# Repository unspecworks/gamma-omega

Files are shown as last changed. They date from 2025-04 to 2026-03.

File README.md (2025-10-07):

# GAMMA OMEGA

A 36 Keys low-profile unibody ergonomic keyboard designed for portability and durability while still maintaining comfort.

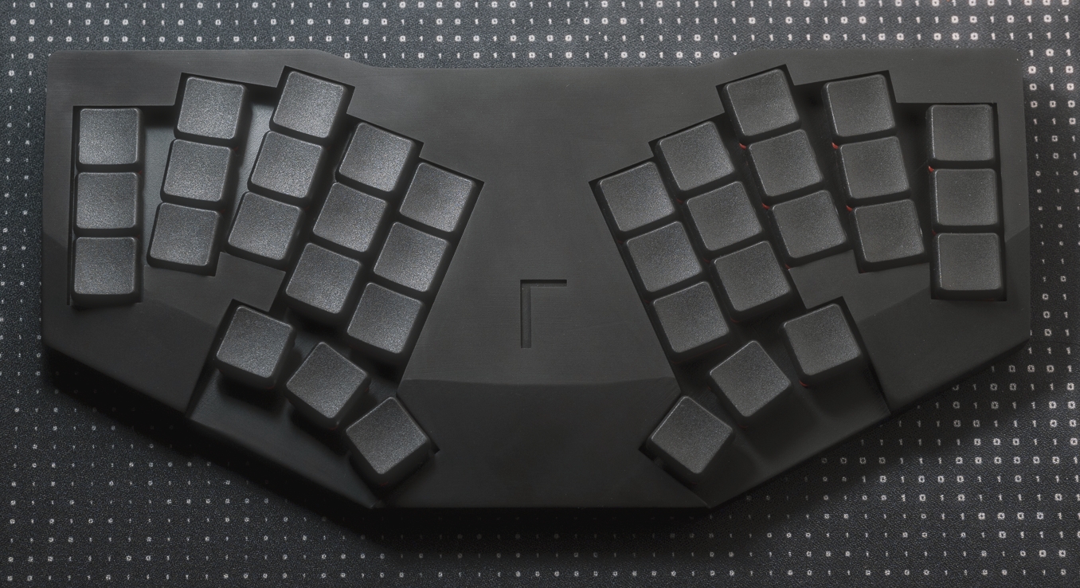
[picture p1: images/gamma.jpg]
Gamma-Omega

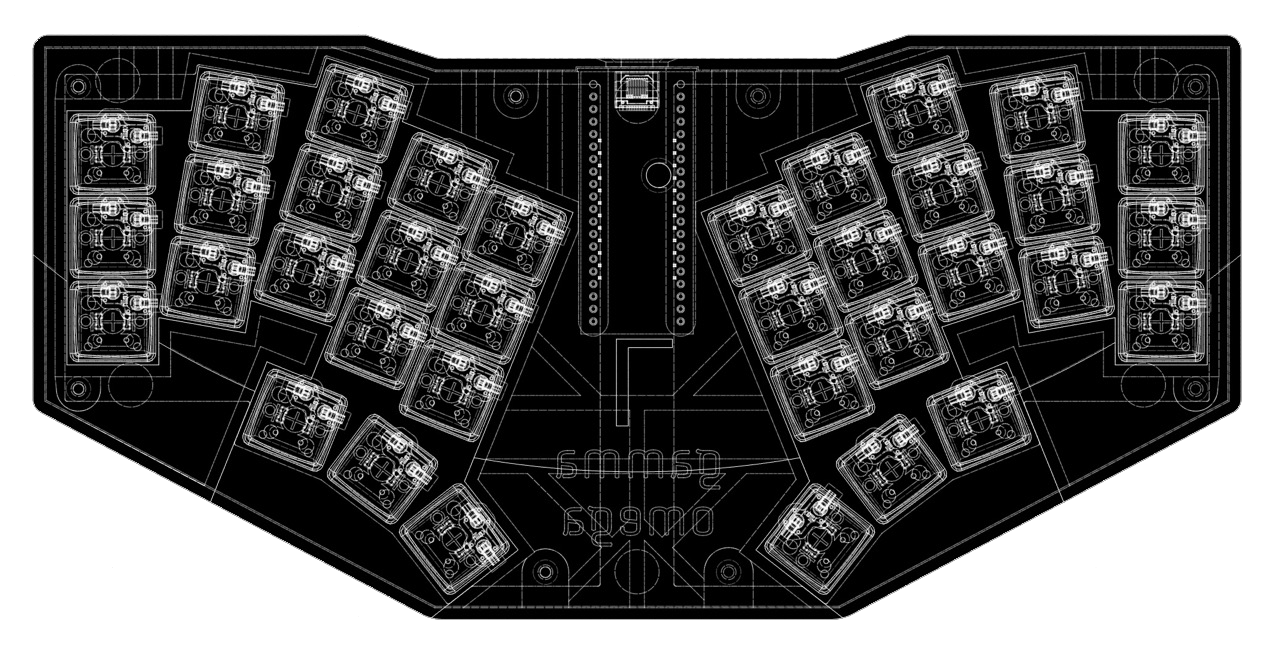
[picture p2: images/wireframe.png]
Gamma-Omega-Wireframe

*Portable? It may not be very compact, but you can still just toss it in your bag, right?*

## Variants
There are currently three variants of Gamma Omega in this repository, all using the same 36-key layout and spacing.

| | Controller | Connection | PCB | Diodes | Roll-over | Switch | Built |
|-|-|-|-|-|-|-|-|
| [Original](/original/) | Raspberry Pi Pico | USB | Twin | 36 | NKRO 🥇 | Choc v1, v2 | :white_check_mark: | 
| [TC36K](/tc36k/) | Raspberry Pi Pico | USB | Mono | 0 | 6KRO 🥈 | Choc v1, v2[^1] | :white_check_mark: |
| [Hesse](/hesse/) | Nice!Nano v2/clone | USB/BLE | Mono | 0 | 4KRO 🥉 | Choc v1, v2 | :construction: |

[^1]: Choc v2 support since the TC36K v1.1.0.

The original and TC36K versions use the same case. The Hesse has a Bluetooth capable MCU controller and a slightly different case for the battery etc.

_See the `README.md` in each folder for more information._

## Technical Details

### Spacing

18 x 17mm (Choc spacing with a tighter grid)

### Dimensions

 - Length: 246mm
 -  Width: 119mm
 - Height: approx. 18mm 
   - feet to keycap (2mm height rubber feet and CFX choc v1 keycap)

### Weight

full built: approx. 301g (Original), 308g (TC36K)

### ergogen

The PCB was generated using [Ergogen](https://github.com/ergogen/ergogen), an ergonomic keyboard generator tool that simplifies the creation of custom keyboard layouts.

## Development Roadmap

- [ ] Support FDM/MJF version case w/ heat set insert method.
- [ ] Cherry MX ULP Switch Variant.

## SPECIAL THANKS 

[@GEIGEIGEIST](https://github.com/GEIGEIGEIST)
- This project was greatly inspired by his work. In particular, TOTEM. [TOTEM](https://github.com/GEIGEIGEIST/totem) is my favorite lo-pro split keyboard. Please check it out.

[Peter Cock](https://github.com/peterjc)
- Thanks for creating and contributing to the TC36k variant.

## Contributing

Contributions are welcome! Feel free to submit pull requests or open issues for any improvements or bug fixes.

The repository uses git-submodules for some footprints, it can easily be setup locally with:

```console
git clone --recurse-submodules https://github.com/unspecworks/gamma-omega.git
```

But I don't know much about modeling and PCB design.

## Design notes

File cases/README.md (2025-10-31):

# Gamma Omega 3DP Case

> [!NOTE]
> Compatible with both [Original](../original/) and [TC36K](../tc36k/) PCBs.

## Bottom case

* **`bottom.step`**
  This version exposes the switch hotswap sockets.

* **`bottom_covered.step`**
  This version conceals the switch hotswap sockets, providing a cleaner appearance.

## Recommendation

For now, it has only been tested with SLA Resin.

### [JLC3DP](https://jlc3dp.com) (JLCPCB)

- 3D Technology: `SLA (Resin)`
- Material: `JLC Black resin`  
- Surface Finish: `General Sanding`

#### If you want the transparent case,

- Material: `8001 Resin`
- Surface Finish: `Oil spray`: Required for full transparency; otherwise the result will be translucent.

> [!TIP]
> You may encounter a few warnings But rest assured, you're good to go.

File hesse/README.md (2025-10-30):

# Gamma-Omega Hesse - BlueTooth mono PCB without diodes

## Quick Links
- [3D Printable Case](cases/) (which are *different* to the original Gamma Omega and TC36K):
- [PCB](pcb/) including the Gerbers ZIP file for getting the PCB fabricated at JLCPLC or similar,
  and BOM & position files which might work for assembly with the hot-swap sockets (untested as the
  parts were not available).
- [Ergogen Configuration](ergogen/README.md) 
- Firmware (which is *different* to the original Gamma Omega and the TC36K):
    - [Hesse ZMK Firmware](https://github.com/peterjc/zmk-keyboard-graph-theory/tree/main/boards/shields/hesse)
- [Build Guide](BUILD_GUIDE.md)

## Photos

Pending, but it looks like the original Gamma Omega - the key placement, PCB outline
and case outline remain the same. However the reset button is now on the top edge along
from the USB connector.

## PCB design

This iteration of the Gamma Omega family of 36-key keyboards is the first wireless one
which supports BlueTooth, specifically BlueTooth Low Energy (BLE) using ZMK firmware.
This meant a change in the controller, as even through the Raspberry Pi Pico W boards
might work, their Bluetooth module is not yet supported in ZMK, and they are much more
battery hungry than the controllers typically used with ZMK.

In order to stick with a diode-free Graph Theory wiring design, I really wanted a
BlueTooth controller with built in LiPo battery charging *and* at least 26 GPIO pins
to follow the same partial *Tutte Coxeter graph* wiring as used in the
[Gamma Omega TC36K](../tc36k/README.md) with 6-key roll over.

Instead, this design uses a [Nice!Nano v2](https://nicekeyboards.com/nice-nano)
or the [SuperMini NRF52840](https://kriscables.com/supermini-nrf52840/) aka
[ProMicro NRF52840](https://www.nologo.tech/product/otherboard/NRF52840.html).
These have built in BlueTooth, LiPo battery charging, ZMK support, but "only"
21 GPIO pins. The compromise means using a bipartite girth 6 graph of 21
vertices and 36 edges, giving *only 4-key roll over*. This is the *Hesse
Configuration Incidence Graph*, also known as the [incidence graph of the
affine plane of order 3](https://houseofgraphs.org/graphs/44164).

It looks like the original Gamma Omega - the key placement, PCB outline and
case outline remain the same. However the case moves the reset button to the
top edge along from the USB connector, and internally adds a battery
compartment. ZMK deep sleep is used in lieu of a physical on/off switch.

## Credits

[triliu/Heawood42](https://github.com/triliu/Heawood42) - the first no-diode keyboard using graph theory (42 key split)

[triliu/JESK56](https://github.com/triliu/JESK56) - later no-diode 56 key monoblock keyboard using graph theory

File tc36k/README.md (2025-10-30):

# Gamma-Omega TC36K - USB mono PCB without diodes

## Quick Links
- [3D Printable Case](../cases/)
- [PCB](pcb/) including the Gerbers ZIP file for getting the PCB fabricated at JLCPLC or similar,
  and BOM & position files which might work for assembly with the hot-swap sockets (untested as the
  parts were not available).
- [Ergogen Configuration](ergogen/README.md) 
- Firmware (which is *different* to the original Gamma Omega):
    - [TC36K QMK/VIAL Implementation](https://github.com/peterjc/qmk_userspace/tree/main/keyboards/tutte_coxeter_36k/)
    - [TC36K ZMK Firmware](https://github.com/peterjc/zmk-keyboard-graph-theory/tree/main/boards/shields/tc36k)
- [Build Guide](BUILD_GUIDE.md)

## Photos

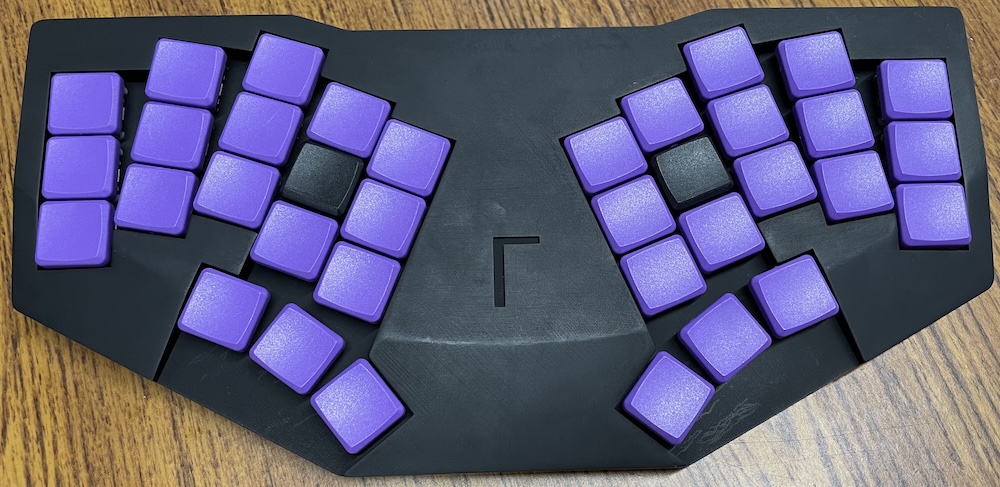
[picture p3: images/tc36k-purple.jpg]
Assembled Gamma Omega TC36K keyboard in black and purple
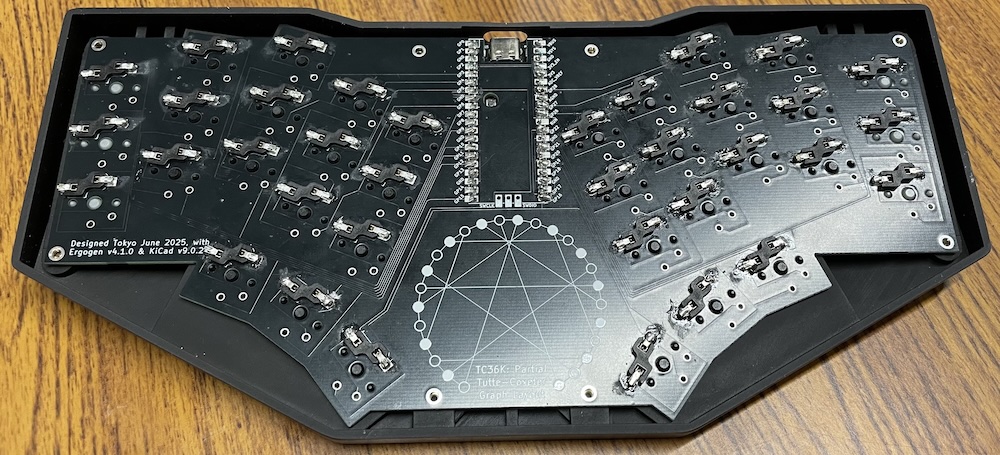
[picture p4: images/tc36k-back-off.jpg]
Inside the Gamma Omega TC36K with the bottom case off showing the no-diode PCB
 

## PCB design

The [original Gamma-Omega](../original/) has a left & right PCB (with the same reversible design),
joined at the middle with the controller daughter board itself.

The *Gamma Omega TC36K* is an alternative larger single PCB design, intended to fit the same case.
Larger PCBs are more expensive, doubly so with the typical minimum order of five - so why do this?
This is a [no-diode design using graph theory to have a 36 key keyboard using only 26 GPIO
pins](https://astrobeano.blogspot.com/2025/05/ergo-mech-keyboard-wiring-using-tutte-coxeter-graph.html).
The cost saving for no diodes is minimal, but with far less parts and soldering,
this design should be quicker and easier to assemble.

Specfically, it uses a partial *Tutte Coxeter graph*, with only 26/30 nodes/vertices/pins,
and 36/45 edges/switches/keys (thus "TC36K"), but still girth 8 for 6-key rollover. 
This needs _different_ firmware to the original Gamma Omega design, see
[Tutte Coxeter 36K firmware (QMK)](https://github.com/peterjc/qmk_userspace/tree/main/keyboards/tutte_coxeter_36k)
or using [ZMK](https://github.com/peterjc/zmk-keyboard-graph-theory/tree/main/boards/shields/tc36k).

## Credits

[triliu/Heawood42](https://github.com/triliu/Heawood42) - the first no-diode keyboard using graph theory (42 key split)

[triliu/JESK56](https://github.com/triliu/JESK56) - later no-diode 56 key monoblock keyboard using graph theory

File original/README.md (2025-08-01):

# Gamma-Omega Original

## Quick Links
- [3D Printable Case](../cases/)
- [PCB](pcb/) 
- [Ergogen Configuration](ergogen/README.md) 
- Firmwares
    - [QMK/VIAL Implementation](firmwares/QMK/gamma_omega/)
    - [ZMK Firmware](https://github.com/unspecworks/zmk-config-gamma-omega)
- [Build Guide](BUILD_GUIDE.md)

## Photos

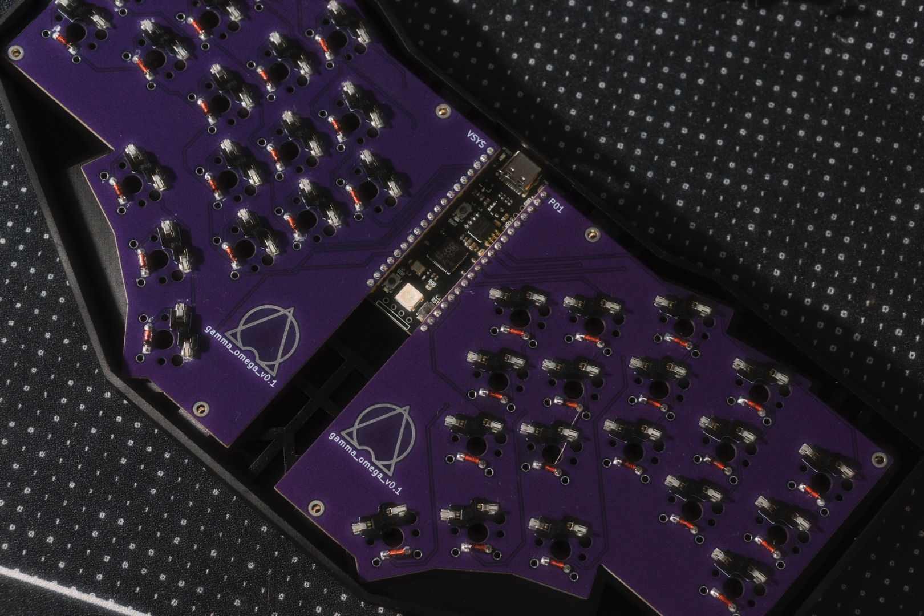
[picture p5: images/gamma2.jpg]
Two PCBs inside the original Gammma Omega
The original Gamma Omega keyboard 

## PCB design

This uses two identical reversible PCBs for the two halves of the keyboard, joined at the RP2040 controller.
This means some pins cannot be used as there isn't a matching pin on the other side,
for example GP0 and GP1 are opposite voltage pins.

This diagram sketches the [GPIO usage](../images/black-raspberry-pi-pico-pins.png)
(red and blue coloring following the convention for the two sides of the PCB).

The design assumes a specific Raspberry Pi Pico variant with GPIOs on pins 35 and 37 (GP29 and GP23),
which are not available on the original board design.
However the pairs GP13/18, GP14/17, and GP15/16 at the bottom of the board are unused,
so in theory the PCB could use those instead for compatibility with the original pin allocation.

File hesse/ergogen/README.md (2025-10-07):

# gamma-omega-hesse - Ergogen files

This is based on the [ergogen](https://github.com/ergogen/ergogen) configuration file
at `../../tc36k/config.yaml` which describes the Gamma-Omega TC36K keyboard mono PCB.
The changes are to use a smaller "Nice!Nano v2" controller (or the "SuperMini NRF52840"
aka "ProMicro52840" clone), which has Bluetooth but less GPIO pins and thus a different
wiring net. We also make a cut out for the inclusion of a battery, and a JST battery
connector, and a reset button (but no power switch in the initial version).
Otherwise the PCB outline and switch placement should be unchanged.

Run ergogen on the whole folder to get it to look at the footprints:

```console
❯ ergogen gc36k/ergogen/
Ergogen v4.1.0 CLI

Analyzing folder...
Interpreting format: YAML
Preprocessing input...
Checking compatibility...
Calculating variables...
Parsing points...
Generating outlines...
Modeling cases...
Scaffolding PCBs...
Writing output to disk...
Done.
```

To merge any changes with the manually routed PCB, try [Ergogen
Helper](https://github.com/infused-kim/kb_ergogen_helper):

```
❯ cp output/pcbs/gamma-omega-hesse.kicad_pcb hesse/pcb/gamma-omega-hesse-routed-new.kicad_pcb && \
    /Applications/KiCad/KiCad.app/Contents/Frameworks/Python.framework/Versions/Current/bin/python3 \
    resources/kb_ergogen_helper/ergogen_helper.py copy-traces \
    hesse/pcb/gamma-omega-hesse-routed.kicad_pcb hesse/pcb/gamma-omega-hesse-routed-new.kicad_pcb
```

## Credits

[triliu/Heawood42](https://github.com/triliu/Heawood42) - the first no-diode keyboard using graph theory (42 key split)

[triliu/JESK56](https://github.com/triliu/JESK56) - later no-diode 56 key monoblock keyboard using graph theory

[infused-kim/kb_ergogen_fp](https://github.com/infused-kim/kb_ergogen_fp) - Awesome footprints and 3d models.

[ceoloide/ergogen-footprints](https://github.com/ceoloide/ergogen-footprints) - Also wonderful footprints!!

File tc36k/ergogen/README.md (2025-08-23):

# gamma-omega-tc36k - Ergogen files

The original Gamma-Omega design has a left & right PCB (with the same reversible design),
joined at the middle with the controller daughter board itself.
The original [ergogen](https://github.com/ergogen/ergogen) configuration file at
`../../original/ergogen/config.yaml` described the Gamma-Omega keyboard double-sided twin PCB design.

That was modified, initially using mirroring to make a single 36 key PCB.
It now uses a full 40-pin Raspberry Pi Pico controller footprint.
That required enlarging the top edge of the PCB by 2mm, which now matches the controller.
This still fits in the same case.
The wiring net is defined using a partial Tutte-Coxeter graph,
with 26/30 nodes/vertices/pins and 36/45 edges/switches/keys.

Run ergogen on the whole folder to get it to look at the footprints:

```console
❯ ergogen tc36k/ergogen/
Ergogen v4.1.0 CLI

Analyzing folder...
Interpreting format: YAML
Preprocessing input...
Checking compatibility...
Calculating variables...
Parsing points...
Generating outlines...
Modeling cases...
Scaffolding PCBs...
Writing output to disk...
Done.
```

## Credits

[triliu/Heawood42](https://github.com/triliu/Heawood42) - the first no-diode keyboard using graph theory (42 key split)

[triliu/JESK56](https://github.com/triliu/JESK56) - later no-diode 56 key monoblock keyboard using graph theory

[infused-kim/kb_ergogen_fp](https://github.com/infused-kim/kb_ergogen_fp) - Awesome footprints and 3d models.

[ceoloide/ergogen-footprints](https://github.com/ceoloide/ergogen-footprints) - Also wonderful footprints!!

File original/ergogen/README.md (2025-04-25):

# gamma-omega ergogen
Configuration files and custom footprints for creating PCBs using [ergogen](https://github.com/ergogen/ergogen).

My custom footprints have many uncommented modifications, so I don't recommend using them separately. Eventually, I plan to organize these properly in a separate repository.

Anyway! Please check out the amazing tool called ergogen and try it for yourself. 

## Credits

[infused-kim/kb_ergogen_fp](https://github.com/infused-kim/kb_ergogen_fp) - Awesome footprints and 3d models.

[ceoloide/ergogen-footprints](https://github.com/ceoloide/ergogen-footprints) - Also wonderful footprints!!

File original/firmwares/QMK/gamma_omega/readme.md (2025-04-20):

# gamma_omega

*A short description of the keyboard/project*

* Keyboard Maintainer: [unspecworks](https://github.com/unspecworks)
* Hardware Supported: *The PCBs, controllers supported*
* Hardware Availability: *Links to where you can find this hardware*

Make example for this keyboard (after setting up your build environment):

    make gamma_omega:default

Flashing example for this keyboard:

    make gamma_omega:default:flash

See the [build environment setup](https://docs.qmk.fm/#/getting_started_build_tools) and the [make instructions](https://docs.qmk.fm/#/getting_started_make_guide) for more information. Brand new to QMK? Start with our [Complete Newbs Guide](https://docs.qmk.fm/#/newbs).

## Bootloader

Enter the bootloader in 3 ways:

* **Bootmagic reset**: Hold down the key at (0,0) in the matrix (usually the top left key or Escape) and plug in the keyboard
* **Physical reset button**: Briefly press the button on the back of the PCB - some may have pads you must short instead
* **Keycode in layout**: Press the key mapped to `QK_BOOT` if it is available

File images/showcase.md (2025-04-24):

# showcase
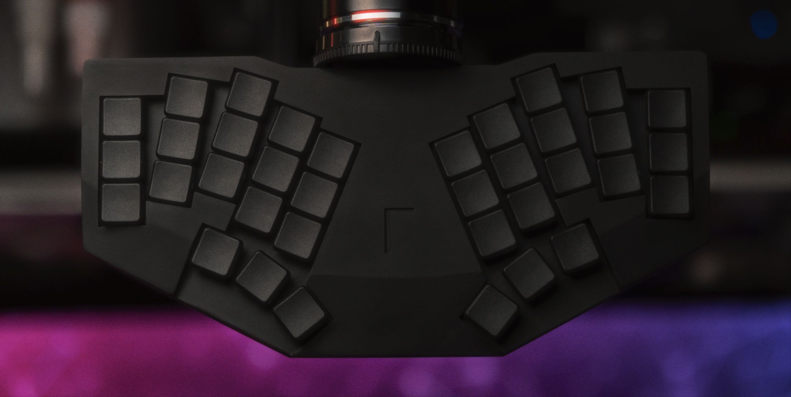
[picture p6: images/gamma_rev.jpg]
hi

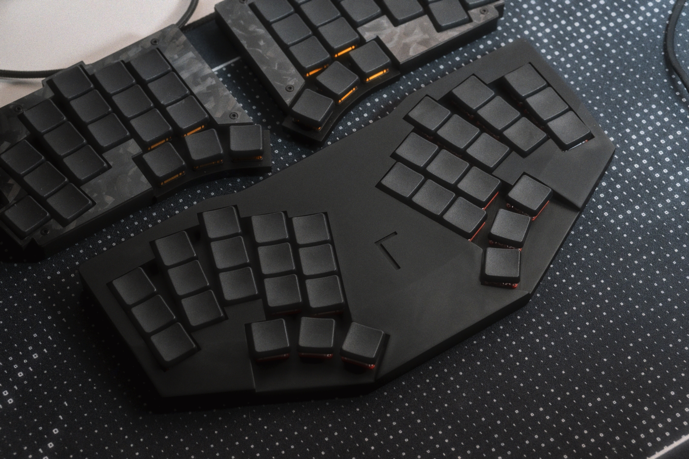
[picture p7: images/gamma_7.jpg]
g

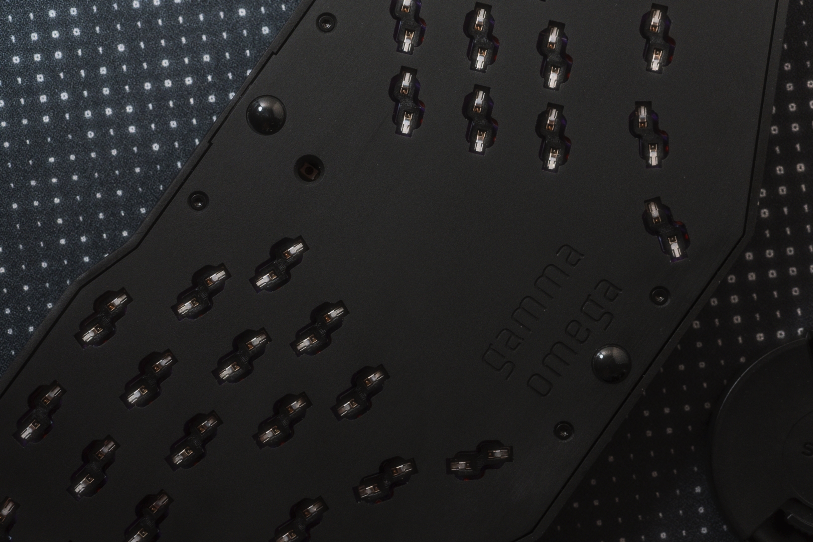
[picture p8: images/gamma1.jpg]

m
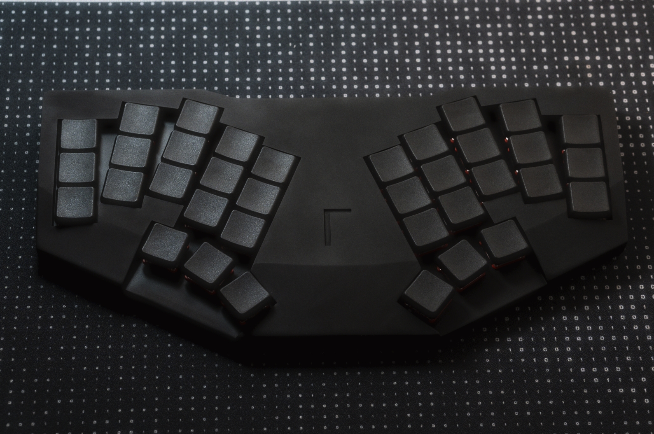
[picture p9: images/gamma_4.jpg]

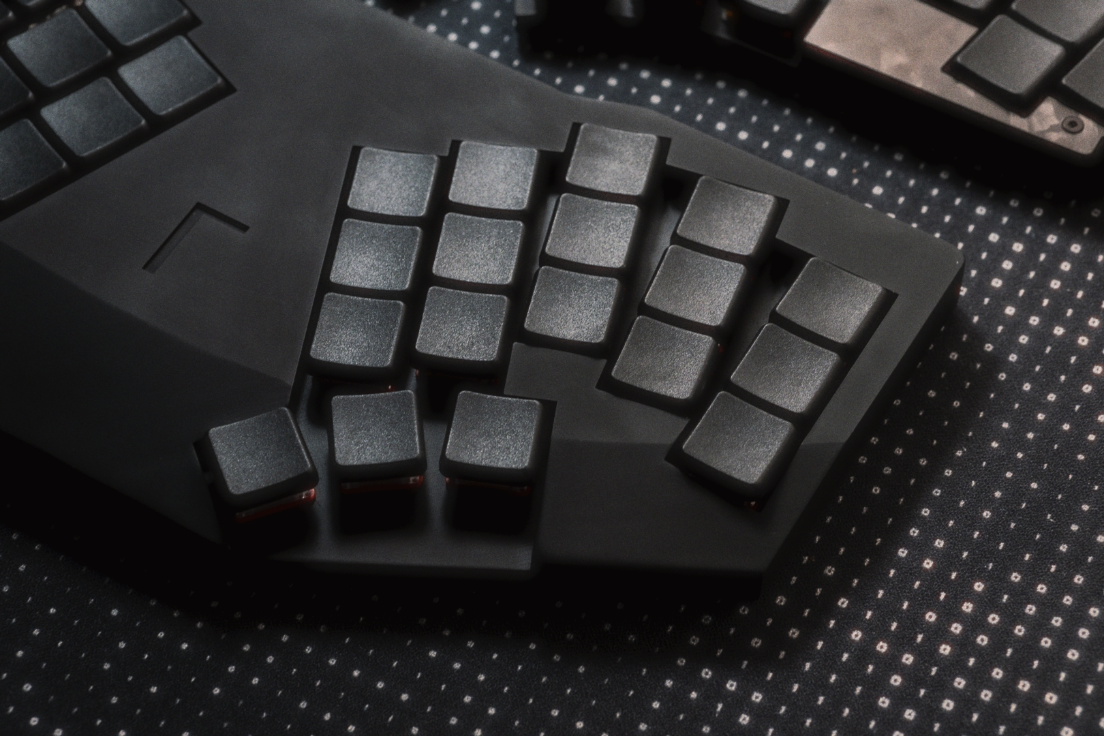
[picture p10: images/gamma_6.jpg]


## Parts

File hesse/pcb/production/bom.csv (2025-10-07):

Designator | Footprint | Quantity | Value | LCSC Part #
JST1 | battery_connector_jst_ph_2 | 1 |  | C157932
RST1 | reset_switch_1825027-8 | 1 |  | C266196
S1, S10, S11, S12, S13, S14, S15, S16, S17, S18, S19, S2, S20, S21, S22, S23, S24, S25, S26, S27, S28, S29, S3, S30, S31, S32, S33, S34, S35, S36, S4, S5, S6, S7, S8, S9 | switch_choc_v1_v2 | 36 |  | C5333465

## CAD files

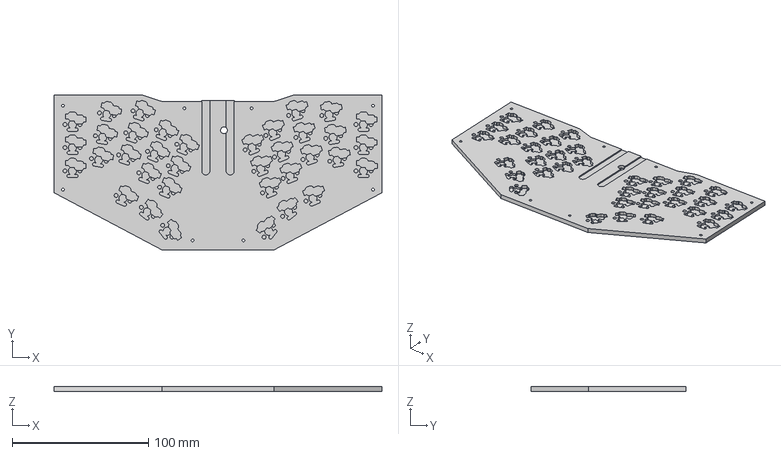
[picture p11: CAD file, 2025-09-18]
cases/bottom_covered.step
240.4 x 113.5 x 3.40 mm

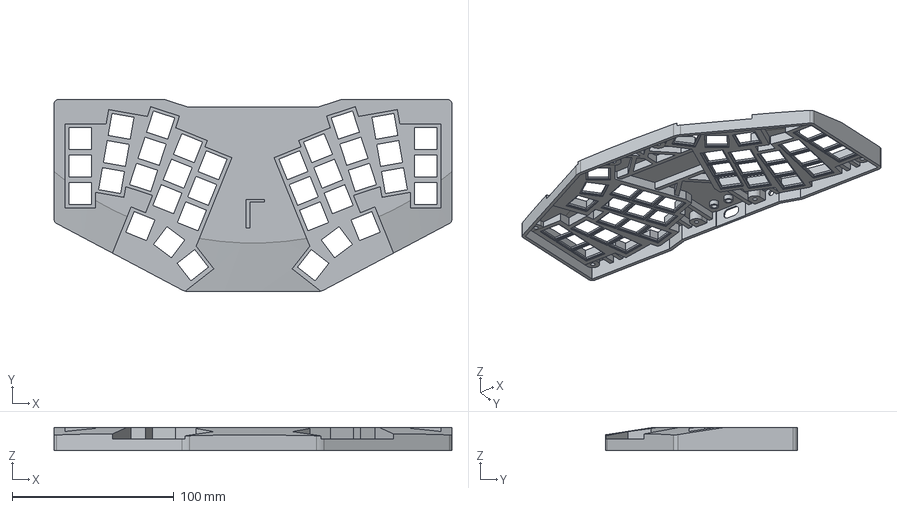
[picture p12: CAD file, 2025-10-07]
hesse/cases/top-hesse.step
245.8 x 118.9 x 14.5 mm

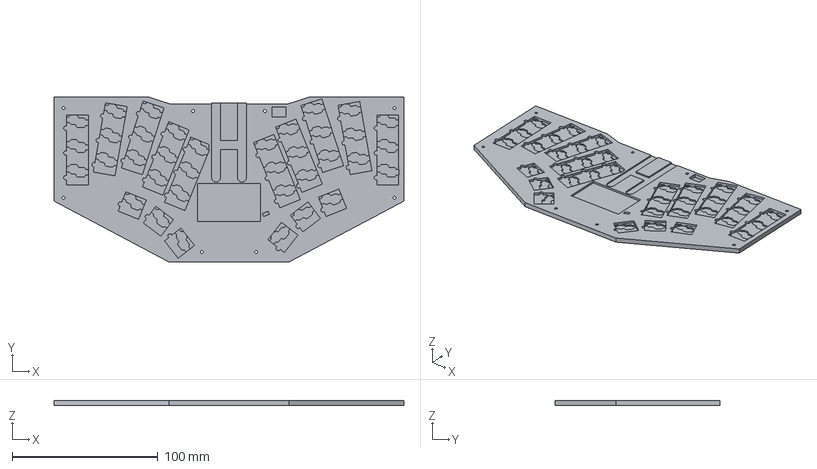
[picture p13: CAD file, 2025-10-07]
hesse/cases/bottom-hesse.step
240.4 x 113.5 x 3.40 mm

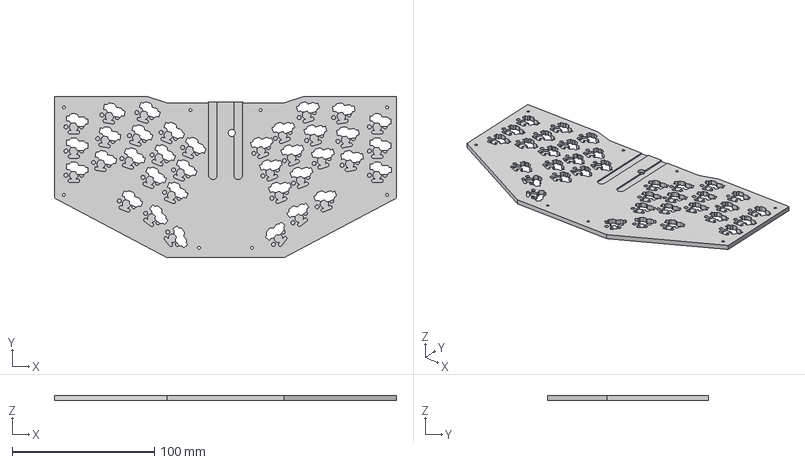
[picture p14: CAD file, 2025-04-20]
cases/bottom.step
240.4 x 113.5 x 3.40 mm

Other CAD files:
cases/top.step

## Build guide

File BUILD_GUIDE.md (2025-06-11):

# Parts List
| Part | Quantity | Details | Source |
|---|---|---|---|
| M2x2 Insert nut | 4 | 2mm length, 3.0mm diameter | |
| M2x6 Insert nut | 4 | 6mm length, 3.0mm diameter | |
| M2x6 Countersunk screw | 4 | 6mm length | |
| M2x8 Countersunk screw | 4 | 8mm length (or 6mm × 8) | |
| Feet bumpons | 6 | 8mm diameter, any height. | |
| 1n4148 diode | 36 |  | [Aliexpress](https://a.aliexpress.com/_oCcCwmR) |
| Kailh Choc PG1350 HotSwap Sockets | 36 | | |
| Kailh Choc switches | 36 | PG1350 | *BUT* |
| Keycap | 36 | MBK, CFX or | |
| Gamma Omega PCB | 2 | 1.6mm thickness | JLCPCB |
| Top case | 1 | SLA Resin | JLC3DP |
| Bottom case | 1 | SLA Resin | JLC3DP |
| Pi Pico USB-C RP2040 | 1 | YD-RP2040 Variants are tested. [Info](https://circuitpython.org/board/vcc_gnd_yd_rp2040/) | [Aliexpress](https://a.aliexpress.com/_opuRQZl) |

> [!NOTE]
> This *requires* a variant of the original Pi Pico design with 28 GPIOs available (GP29 and GP23 on pins 35 and 37).
> The bottom case has a hole allowing access to the boot button on the RP2040 controller, which is mounted facing down once fully assembled.
> The placement of any boot/reset/user buttons varies between boards, even if they are pin-compatible.
> The expected placement (looking at the controller chips upward with the USB and pin 1 at the top) is on the left near pins 7, 8 & 9 (GP5, GND & GP6).
> This is the "black" controller at the Ali Express link:
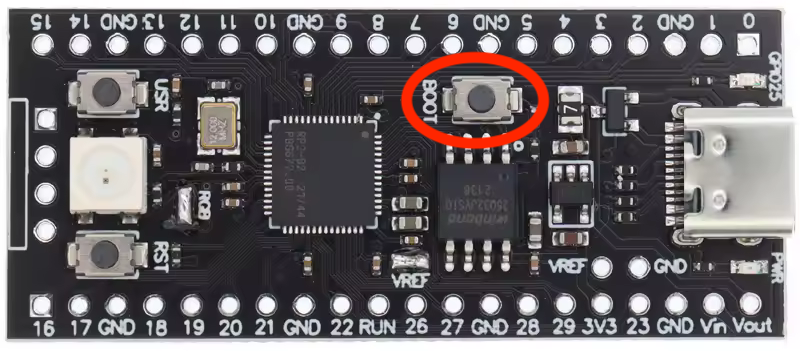
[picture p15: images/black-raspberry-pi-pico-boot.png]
YD_PR2040 "black" Pi Pico microcontroller
> 

> [!TIP]
> Actually, the PCB is compatible with choc v2 and Lofree POM switches. However, since the key spacing is 18x17mm, there may be issues with keycap compatibility. Please keep this in mind.

## Tools

- Soldering tools.
- Safety gears.
- epoxy adhesive
    - or cyanoacrylate adhesive would be fine too for fixing inserts.

> [!WARNING]
> For your safety: Wear protective eyewear, be cautious of hot components, and ensure proper ventilation to avoid inhaling toxic fumes.

# Build Guide

## Diodes Installation
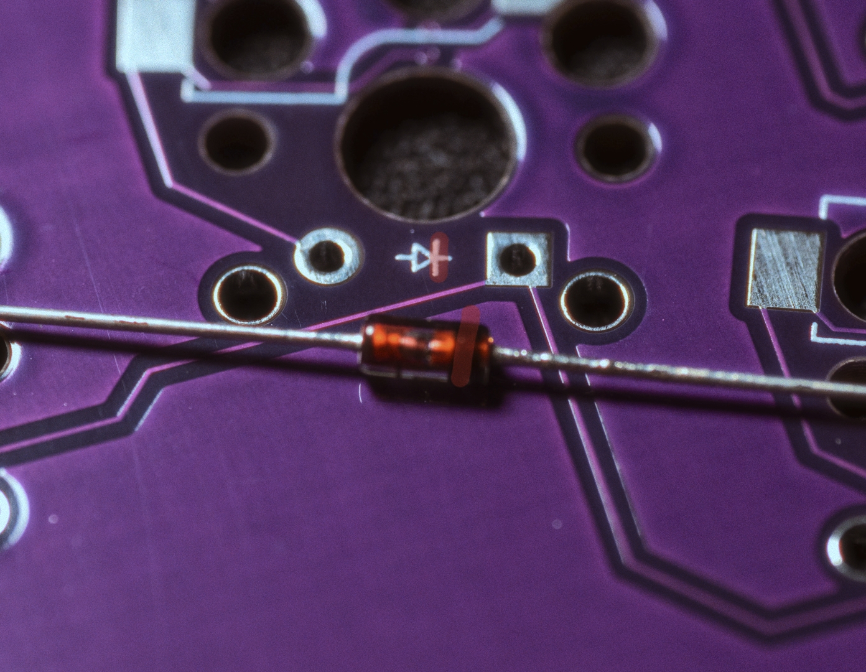
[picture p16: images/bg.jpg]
Diode

> [!IMPORTANT]
> Install diodes with their direction matching the PCB silkscreen markings

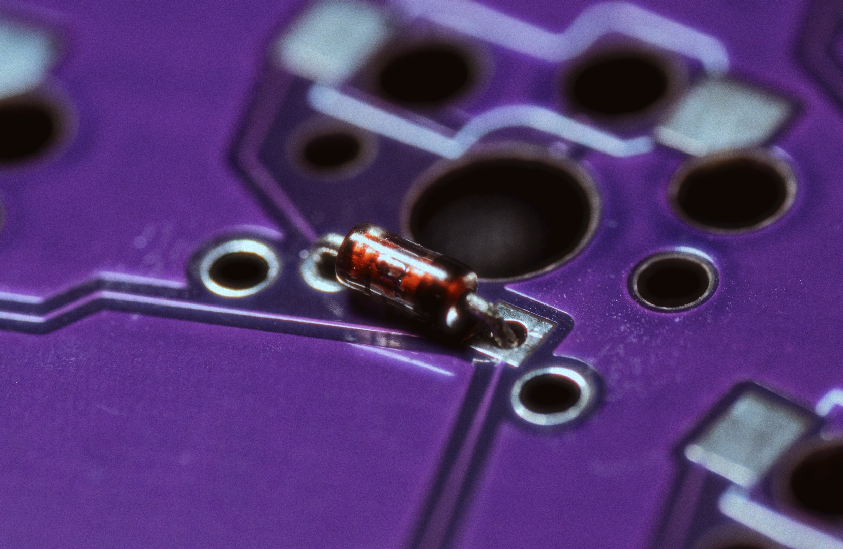
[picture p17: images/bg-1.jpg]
diode2

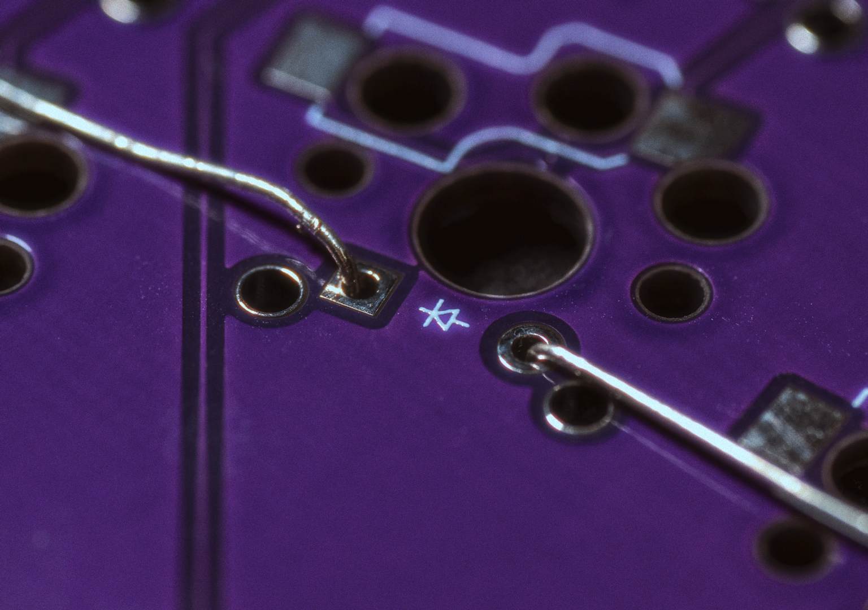
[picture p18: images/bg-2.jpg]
diode3


1. Install diodes carefully, paying close attention to the correct orientation.
2. The direction of the diode must match the silkscreen markings on the PCB.
3. Ensure all diodes are mounted flat against the PCB and aligned straight between the holes.

## Hotswap Socket Installation
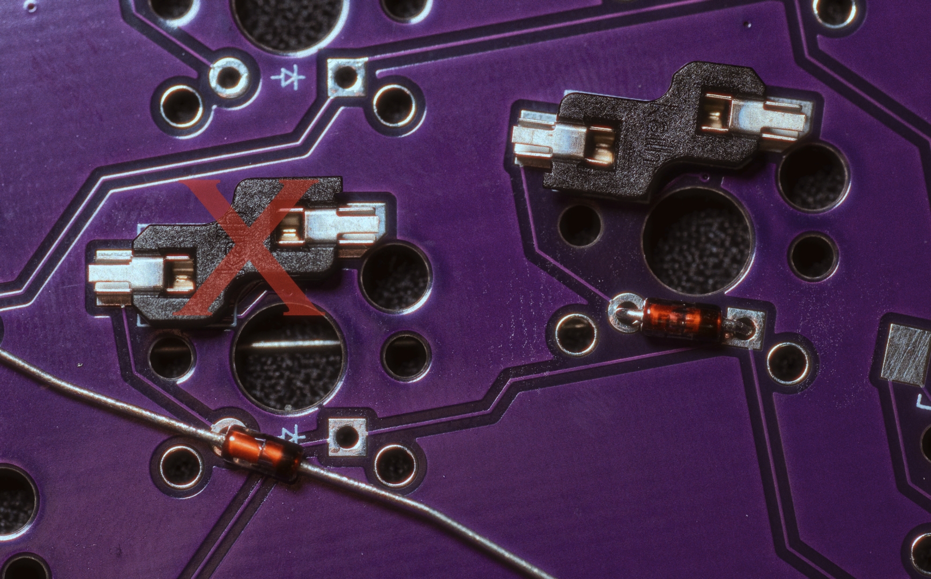
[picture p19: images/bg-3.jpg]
hotswap


1. Install hotswap sockets according to the PCB markings.
2. Ensure correct orientation of the sockets; while they can physically fit in either direction, the bottom case cutouts are designed for the correct orientation only.

## Pi Pico Installation
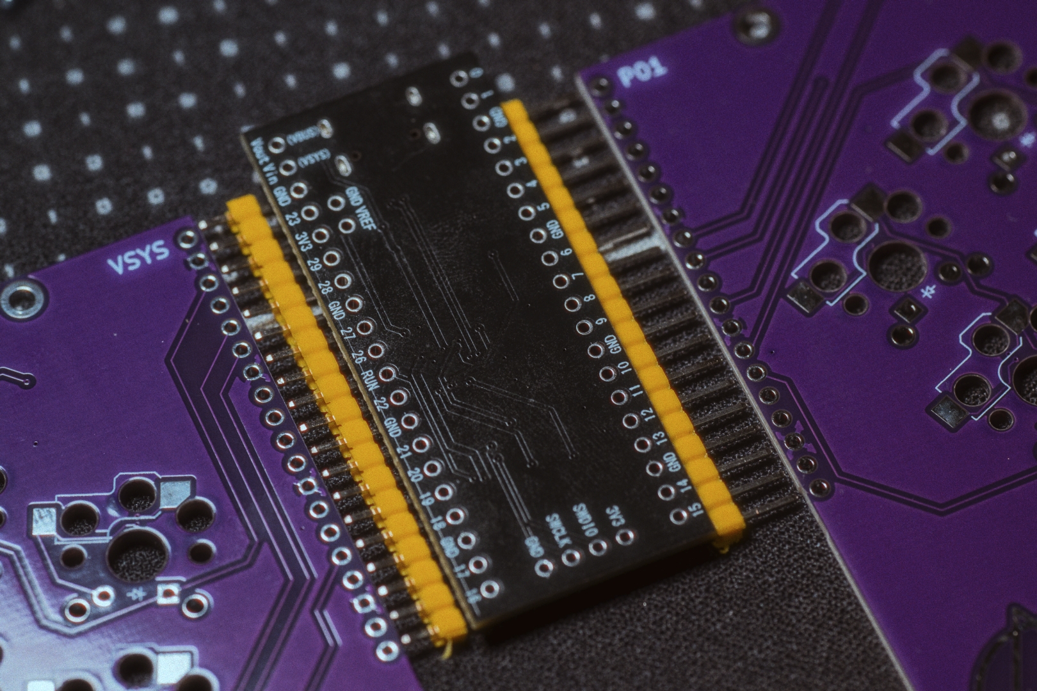
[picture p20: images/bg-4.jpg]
pico


1. Install the Pi Pico on the UP side of the PCB (opposite from where sockets and diodes are installed).
2. Position the Pi Pico with its components facing down toward the PCB and the USB port facing outward.
3. Use two 2.54mm × 19-pin headers (typically with ~2.5mm height insulators) to solder the Pi Pico onto the PCB.

> [!NOTE]
> Do not solder the top left and right pins (the ones closest to the USB port).

> [!WARNING]
> Once soldered, the two PCBs are held together by only a few points. Please be careful when handling them, as they can be easily damaged before being placed in the case

4. After soldering, carefully trim all protruding pins with a nipper.

> [!CAUTION]
> For your safety, please wear safety glasses — trimmed pins can be sharp and may fly off during cutting.

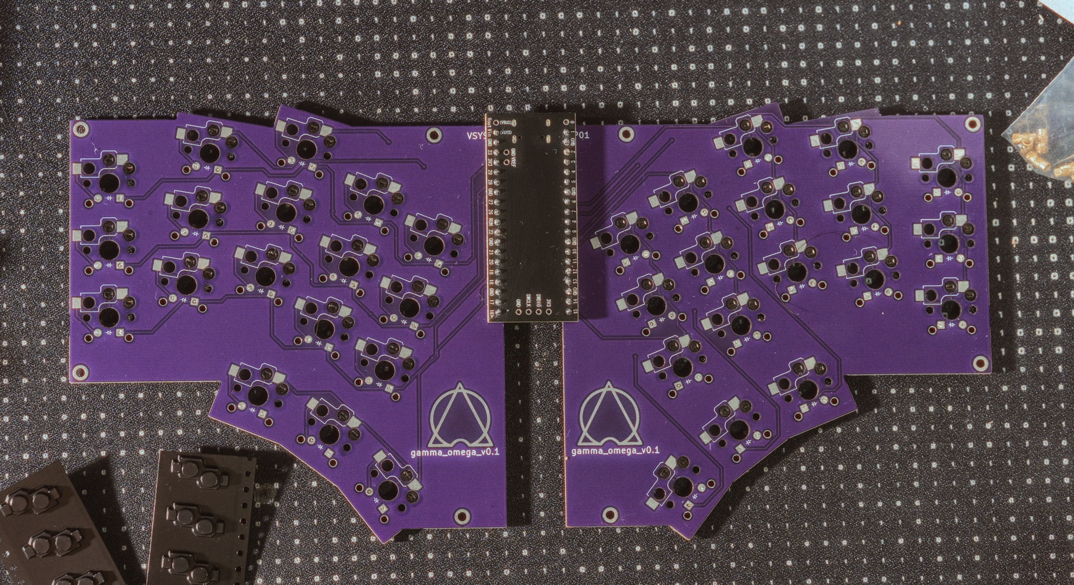
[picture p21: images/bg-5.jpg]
final-pcb

*Your PCB should look like this when completed*

## Firmware Flashing
1. Press and hold the `BOOT` button while connecting the keyboard to your computer.
2. Release the `BOOT` button when a Mass Storage device named "RPI-RP2" appears.
3. Copy the `gamma_omega_vial.uf2` firmware file to this storage device.
4. The storage will disconnect automatically, and the device will function as a keyboard when the firmware is successfully installed.

## Testing
Use your favorite keystroke tester (or Vial's Key matrix tester) with a conductive tweezer to verify that all keys are working properly.

## Case Assembly
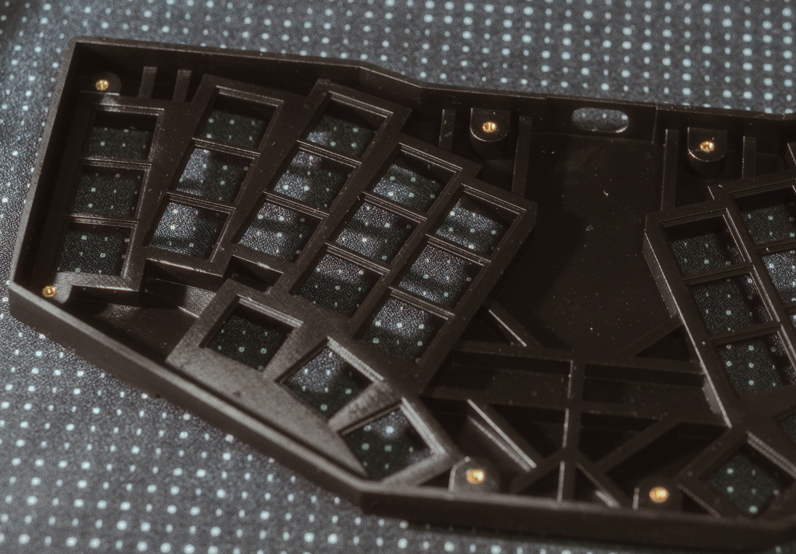
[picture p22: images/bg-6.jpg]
topcase


1. Install 6mm threaded inserts with epoxy adhesive on the top case (upper side, near the USB port hole).
2. Install 2mm threaded inserts with epoxy adhesive on the top case (lower side, opposite the USB port hole).

put-pcb

3. Place the PCB onto the top case.
4. Install switches into the top case while holding the PCB (hotswap sockets) in place.
5. Place the bottom case onto the top case assembly.
6. Secure with screws (8mm or 6mm for upper side, 6mm for lower side).
> [!CAUTION]
> Do not overtighten: the screws only need to support the bottom case's weight.

## DONE!
back
front

### Everything is done.

how does it feel? Comfortable? Any issues? Does it work as you expected?

Whatever the result, I’d really appreciate it if you shared your experience with the community.

Thank you for building it!

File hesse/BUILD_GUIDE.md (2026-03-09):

# Hesse Build guide

Looking for the [original's build guide](../original/BUILD_GUIDE.md),
or the [TC36K's build guide](../tc36k/BUILD_GUIDE.md)?

# Parts List
| Part | Quantity | Details | Source |
|---|---|---|---|
| M2x2x3 Insert nut | 4 | M2 thread, 2mm length, 3.0mm outer diameter | |
| M2x6x3 Insert nut | 4 | M2 thread, 6mm length, 3.0mm outer diameter | |
| M2x6 Countersunk screw | 4 | 6mm length | |
| M2x8 Countersunk screw | 4 | 8mm length (or 6mm × 8) | |
| Feet bumpons | 6 | 8mm diameter, any height. | |
| Kailh Choc PG1350 HotSwap Sockets | 36 | 💡 |
| Kailh Choc switches | 36 | PG1350 | 💡 |
| Keycap | 36 | MBK, CFX, THCS, ... | |
| Gamma Omega Hesse PCB | 1 | 1.6mm thickness | JLCPCB |
| Hesse Top case | 1 | SLA Resin | JLC3DP |
| Hesse Bottom case | 1 | SLA Resin | JLC3DP |
| 6x6x8H right angle reset switch | 1 | 90 degree reset switch like [Tyco Electronics (TE) 1825027-8](https://www.te.com/en/product-1825027-8.html), with a sideways 6x6mm base and 8mm from back of base to end of the button. | e.g. [AliExpress](https://www.aliexpress.com/item/4000275201465.html) |
| JST connector | 1 | JST PH 2.0mm | |
| 3.7V LiPo battery | 1 | eg 500mAh LP702035 with JST connector | 💡 |
| Nice!Nano v2 or clone | 1 | The [SuperMini NRF52840](https://kriscables.com/supermini-nrf52840/) aka [ProMicro NRF52840](https://www.nologo.tech/product/otherboard/NRF52840.html) is tested. | [Offical](https://nicekeyboards.com/nice-nano#find-a-store), [AliExpress](https://www.aliexpress.com/item/1005006035267231.html) |
| Pin headers/diode legs | 35+ | Use the headers included with the controller |  |

> [!WARNING]
> The PCB design mounts the controller face up directly on the PCB, faux-castellated style.
> This is not easy for a novice at soldering.

> [!NOTE]
> The mounting holes for the extra middle trio of pins are different between the Nice!Nano v2 and clones.
> Using a clone controller requires bridging this with bent pins.

> [!NOTE]
> No-stabilizer Choc v2 switches work too, the central hole is large enough.
> However, since the key spacing is 18x17mm, there are not many compatible keycaps.
> Consider the Tai Hao "THCS" or square "MT 165" with the cross stem option.

> [!TIP]
> This PCB allows directly soldering the choc switches (rotated 180 degrees) without using hot-swap sockets.
> However, that will not work with the suggested case bottom (which has hot-swap cut-outs).

> [!TIP]
> The battery compartment will take a 300mAh LP602030 3.7V LiPo battery with ample space to spare.
> A 500mAh LP702035 500mAh should fit comfortably and is suggested, but as yet untested.
> If you want so push it, the largest that might fit is probably a LP802040 - 650mAh,
> again please let us know how that goes if you try.

> [!TIP]
> 3D printing varies, but with my case the 6x6x7H right angle switch was too short, and while
> the 6x6x8H is easy to press it sticks out a fraction. The in-between 7.5mm version might be
> a better choice (untested).

## Tools

- Soldering tools.
- Safety gears.
- Wire cutters (to trim controller header pins).
- Circuit tester.
- USB cable and computer (for flashing the controller).
- epoxy adhesive (or cyanoacrylate adhesive) for fixing insert nuts.

> [!WARNING]
> For your safety: Wear protective eyewear, be cautious of hot components, and ensure proper ventilation to avoid inhaling toxic fumes.

## Firmware Flashing

1. Download the [hesse-nice_nano_v2-zmk.uf2](https://github.com/peterjc/zmk-keyboard-graph-theory/releases/download/latest/hesse-nice_nano_v2-zmk.uf2) firmware.
2. Connect the controller. The official Nice!Nano v2 is not expected to do this,
but the clones *may* be pre-loaded with a blink program that does this:
  * Left LED flashes once a second.
  * Right LED turns on or off every second.
  * With a multimeter check all 21 GPIO pins cycle from 0 to 3.3V once a second.
3. Short the reset pin (RST) to any of the ground pins (GND) twice in a second (just tap a few times).
4. USB Mass Storage device named `NICENANO` appears.
5. Copy the `hesse-nice_nano_v2-zmk.uf2` firmware file to this storage device.
  * On macOS you may get a error code -36 about failing to complete. This seems to be harmless.
6. The storage will disconnect automatically.
  * On macOS you well get a notification recommending unmounting before disconnecting.
7. The device should now function as a keyboard.
  * The battery charging LED will continue to flash with no battery connected.
  * You can try shorting pins like `D1/P0.06` and `D0/P0.08` top left which should type Qwerty `E`.
7. Disconnect the USB cable to the controller.

> [!TIP]
> It is a little fiddly without a reset button, but flashing *before* soldering to
> the PCB should catch a bad controller early on.

## Nice!Nano v2 or Clone Installation

We will install the controller face up on the UP side of the PCB
(opposite from where hotswap sockets will be installed), with the LEDs facing the user.

1. Break the two long header pins into blocks of three or four pins (to make removal easier later).
2. Push the pins further through the blocks, leaving about 2mm at the short end.
3. Solder these into the PCB with the block and long ends facing up.

Hesse PCB (purple) with most of the two outer rows on pins in place with their header block still attached

4. Place the PCB in the bottom case to check the short pins don't stick out too much.
5. Solder the short pins on the back (same side as the hotswap pads).
6. Test things so far:
  * Carefully thread the controller onto the long pins.
  * Tilt the controller at slight angle to help ensure connections.
  * Plug in the USB and test shorting each key's switch.
  * The right thumbs and two right-most columns can be tested using the three middle pins.
  * Unplug the USB.

Hesse PCB (purple) with clone controller (red) on the pins, tilted

7. Remove the controller, remove the header blocks with pliers.
8. Straighten the pins, and fix any lost pins individually.
9. Again carefully thread the controller onto the long pins, flat on the PCB this time.
10. Clip the pins to at most 2mm above the controller.

> [!CAUTION]
> For your safety, please do this in a bag and/or wear safety glasses — trimmed pins can be sharp and may fly off during cutting.

11. Solder the controller pins using as little solder as possible.
12. Connect the USB, retest, unplug.
13. Solder the last three pins in the middle.
  * Use a similar technique with the official Nice!Nano v2 controller
  * For the clones, use needle nose pliers to pre-bend three pins into a staple-like hook.
    Aim for a short leg of about 1.5mm, then about 2mm horizontal, leaving a long leg down.
    This must not stick up too much or it will block the top case.
    Solder the three pins one-by-one, starting with the small leg in the controller.

Three pins bent ready to connect the middle pins on a clone controller

14. After soldering, check the case fitting, and carefully trim any protruding pins with a nipper.

## Test Soldered Controller

Connect the USB-C port on the controller mounted on the PCB, and it should still register as a keyboard.
The power LED will be flashing (since there is no battery yet).

Use your favorite keystroke tester with conductive tweezers to verify that all keys are working properly.

## Hotswap Socket Installation

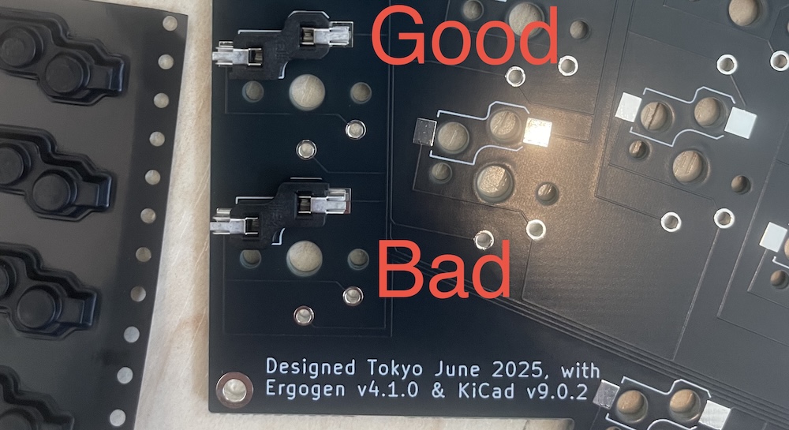
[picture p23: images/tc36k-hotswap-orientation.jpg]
Hotswap switch orientation


1. Install hotswap sockets according to the PCB markings.
2. Ensure correct orientation of the sockets; while they can physically fit in either direction, the bottom case cutouts are designed for the correct orientation only.
3. Test the soldered connection of each hotswap pad with a circuit tester using the 180-degree rotated direct solder holes. That's 72 tests, but very easy!

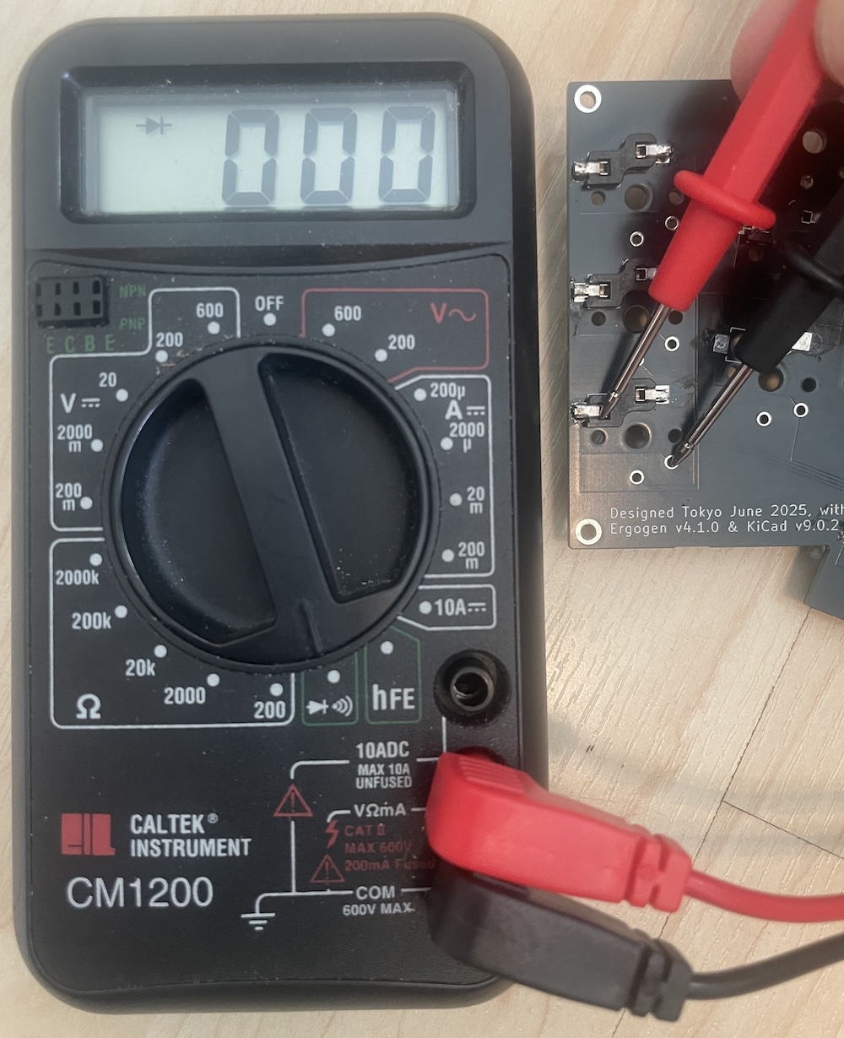
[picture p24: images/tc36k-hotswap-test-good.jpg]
Good circuit-test of hotswap

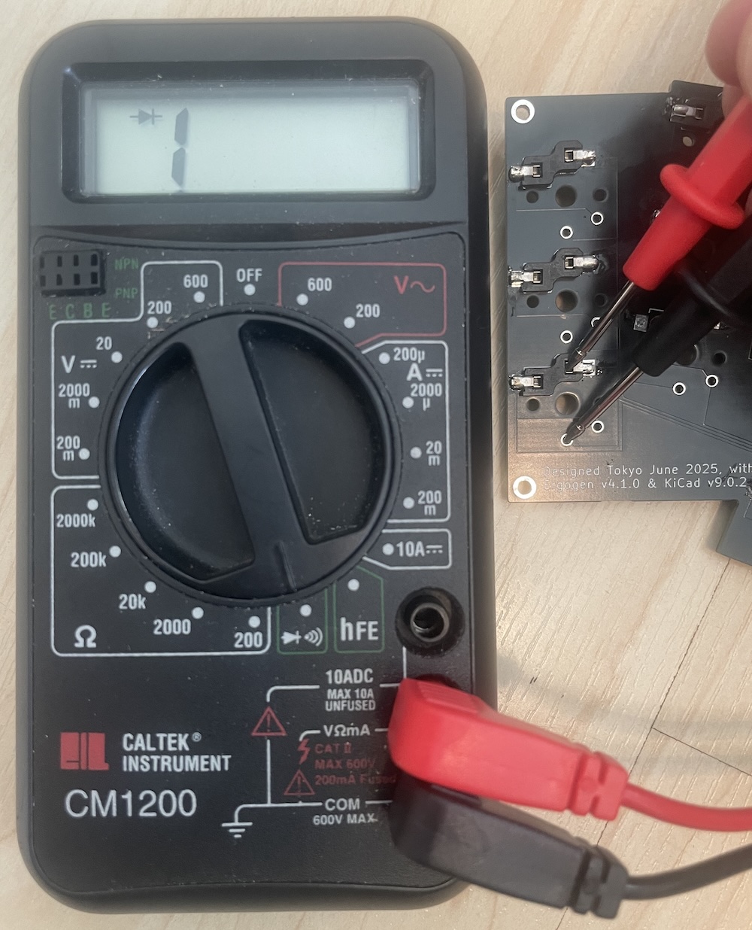
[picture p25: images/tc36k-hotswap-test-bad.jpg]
Failing circuit-test of hotswap


## Reset Button

> [!TIP]
> If you have several sizes, please do a trial fit of the switch, PCB, and top case to pick
> the best button length. For me the 7mm was too short, and the 8mm sticks out a fraction,
> so the 7.5mm version could be better?

1. Insert the right angle reset button from the front side (which has the controller).
2. Once clicked into place, temporarily insert the PCB into the top case to confirm the shaft length.
2. Solder the four legs from the back (the side which has the hotswaps).

## Battery Connection

The connector  will be on the top (like the controller), but the two legs are soldered from the bottom.
This is a standard through hole component, and should be easily soldered.

Before assembly, test connecting the battery cable connector to the JST socket.
Make sure the red wire matches positive on both PCB (remember it sits on the top side) and on the battery markings.
Likewise, check the black wire matches negative on the PCB and on the battery markings.

Get a feel for the force needed to connect and disconnect it. Do not pull the wires, pull the plug.

1. Test the battery plug fits the JST connector, then disconnect it.
2. Insert the JST connector into the PCB from the front side (which has the controller),
3. Solder the two legs from the back (the side which has the hotswaps).

## PCB Done

Your PCB should look like this when completed:

Hesse PCB (purple) with clone controller (red), reset switch, and JST battery connector

## Battery Testing

1. With the controller NOT connected by USB, connect the battery using the JST socket.

> [!TIP]
> The battery may be empty on shipping, so we don't expect anything to happen when connecting it.

2. Connect the USB port.
3. The battery should start charging - note the change in the LED to solid on.
4. The keyboard should be broadcasting as "Hesse" on Bluetooth.
5. Wait a few minutes, monitor the battery for signs of overheating.
6. Disconnect the USB.
7. Check "Hesse" is still advertised on Bluetooth.
8. Disconnect the battery, or continue to case assembly.

## Case Assembly
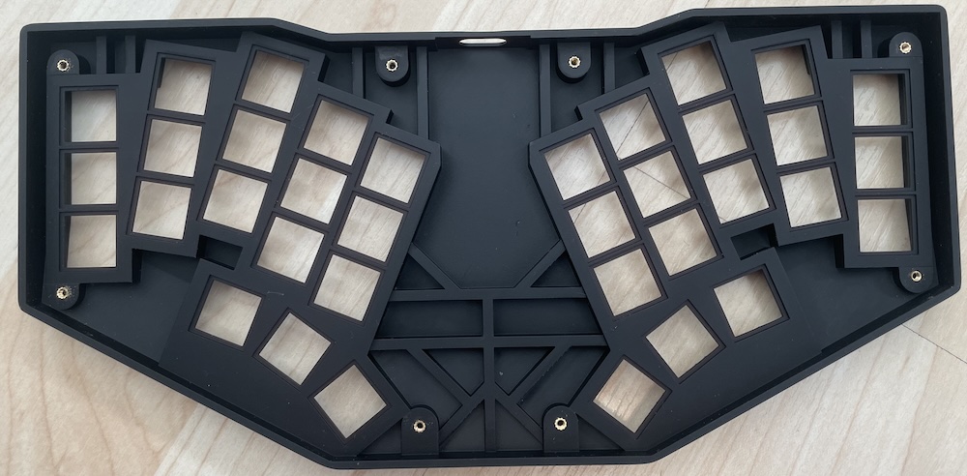
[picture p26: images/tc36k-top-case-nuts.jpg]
Install the nuts (as in the other cases)


1. Install 6mm threaded inserts with epoxy adhesive on the top case (upper side, near the USB port hole).
2. Install 2mm threaded inserts with epoxy adhesive on the top case (lower side, opposite the USB port hole).

> [!TIP]
> You may not need the glue, mine seems fine with friction alone.

3. (Re)connect the battery, keep it on the hotswap side with the wire though the battery cutout.
4. Place the PCB into the top case, taking care to align the reset button and USB port (battery free on top).
5. Place battery into the compartment, rotated to place no stress on the cable.

Hesse PCB (purple) with battery connected, inside the top case

6. Install switches into the top case while holding the PCB and hotswap sockets in place.
7. Adjust battery and wire to fit inside.

Hesse PCB (purple) with battery connected inside the top case (black), with the bottom case (white) above

8. Place the bottom case onto the top case assembly.
9. Secure with screws (8mm or 6mm for upper side, 6mm for lower side).

> [!TIP]
> Do not over-tighten: the screws should only need to support the bottom case's weight.

> [!CAUTION]
> If the top case has warped ever so slightly, then the switches and outer screws should bend it straight.

10. Apply the six feet bumpon stickers to the sunken circles on the case bottom.

Underside of Hesse (top in black resin, bottom in white resin) with black bumpons

11. Give it a test (sometimes hotswaps can be loosened by the switch), then add the keycaps.

## DONE!

Here is my Hesse with a black resin case, Kailh Choc v1 50g 'red' switches, and Chosfox CFX
keycaps (which are square and slightly narrower). This used black blanks for the home row and
thumbs, orange for the top and bottom on the left, and pale blue for top and bottom on the right.
I used homing keys for the index and pinky fingers, and am using wider 1.25u keycaps for the
middle thumb buttons and the S and L keys.
This is plugged in and charging with a matching blue USB cable:

Assembled Hesse keyboard in black with black/orange/blue Chosfox CFX keycaps

The power LED (blue on the clone controllers) can be easily seen through the black resin case.
The red user LEDs is more muted.

And here is the same black keyboard with 35g Kailh Islet Pink Mini Low Profile Silent Linear
Switches (which are Choc v2 with the cross stem), and the very flat Tai-Hao THCS keycaps in
their greenish grey 'Navy' option. They currently do not offer any homing keys in this size:

Assembled Hesse keyboard in black with 'Navy' Tai-Hao THCS keycaps

### Everything is done.

The keyboard should work as a USB keyboard while plugged in, and will charge the battery.
See the ZMK documentation for handling Bluetooth connections.

How does it feel? Comfortable? Any issues? Does it work as you expected?

Whatever the result, we’d really appreciate it if you shared your experience with the community.

Thank you for building it!

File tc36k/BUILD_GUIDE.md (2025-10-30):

# TC36k Build guide

[Looking for the original's build guide?](../original/BUILD_GUIDE.md)

# Parts List
| Part | Quantity | Details | Source |
|---|---|---|---|
| M2x2x3 Insert nut | 4 | M2 thread, 2mm length, 3.0mm outer diameter | |
| M2x6x3 Insert nut | 4 | M2 thread, 6mm length, 3.0mm outer diameter | |
| M2x6 Countersunk screw | 4 | 6mm length | |
| M2x8 Countersunk screw | 4 | 8mm length (or 6mm × 8) | |
| Feet bumpons | 6 | 8mm diameter, any height. | |
| Kailh Choc PG1350 HotSwap Sockets | 36 | 💡 | |
| Kailh Choc switches | 36 | PG1350 | ⚠️ |
| Keycap | 36 | MBK, CFX, ... | |
| Gamma Omega TC36K PCB | 1 | 1.6mm thickness | JLCPCB |
| Top case | 1 | SLA Resin | JLC3DP |
| Bottom case | 1 | SLA Resin | JLC3DP |
| Pi Pico USB-C RP2040 | 1 | YD-RP2040 Variants are tested. [Info](https://circuitpython.org/board/vcc_gnd_yd_rp2040/) | [Aliexpress](https://a.aliexpress.com/_opuRQZl) ⚠️ |
| 20-pin headers |  2 | Included with RP2040, ~2.5mm insulation height |  |

> [!NOTE]
> The bottom case and PCB has a hole allowing access to the boot button on the RP2040 controller, which is mounted facing down once fully assembled.
> The placement of any boot/reset/user buttons varies between boards, even if they are pin-compatible.
> The expected placement (looking at the controller chips upward with the USB and pin 1 at the top) is on the left near pins 7, 8 & 9 (GP5, GND & GP6).
> This is the "black" controller at the Ali Express link:
> YD_PR2040 "black" Pi Pico microcontroller
>
> This Pi Pico variant has 28 GPIOs available (GP29 and GP23 on pins 35 and 37),
> required in the original Gamma Omega dual PCB design, but which are unused in the TC36K PCB.
> As long as you don't care about the boot button, standard 26 GPIO Pi Pico designs *should* be fine (untested).

> [!NOTE]
> As of PCB v1.1.0, the central hole for each switch has been enlarged and should be
> compatible with choc v1 or v2 switches with no stabilizer pin.
> However, since the key spacing is 18x17mm, there are not many compatible keycaps
> for the Mx style stem on the choc v2 switches.

> [!TIP]
> This PCB allows directly soldering the choc switches (rotated 180 degress) without using hot-swap sockets.
> However, that will not work with the suggested case bottom (which has hot-swap cut-outs).

## Tools

- Soldering tools.
- Safety gears.
- Wire cutters (to trim controller header pins).
- Circuit tester.
- USB cable and computer (for flashing the controller).
- epoxy adhesive (or cyanoacrylate adhesive) for fixing insert nuts.

> [!WARNING]
> For your safety: Wear protective eyewear, be cautious of hot components, and ensure proper ventilation to avoid inhaling toxic fumes.

## Firmware Flashing
1. Download the [tutte_coxeter_36k_vial.uf2](https://github.com/peterjc/qmk_userspace/releases/download/release-2025-10-30/tutte_coxeter_36k_vial.uf2) firmware.
2. Press and hold the `BOOT` button while connecting the controller to your computer by USB.
3. Release the `BOOT` button when a Mass Storage device named "RPI-RP2" appears.
4. Copy the `tutte_coxeter_36k_vial.uf2` firmware file to this storage device.
5. The storage will disconnect automatically, and the device will function as a keyboard when the firmware is successfully installed.
6. Try toggling CAPS LOCK on your main keyboard, the blue LED on the controller by the USB socket (opposite the red power LED) should come on.
7. Disconnect the USB cable to the controller.

> [!TIP]
> Flashing *before* soldering in the PCB should catch a bad controller early on.

## Hotswap Socket Installation
Hotswap switch orientation

1. Install hotswap sockets according to the PCB markings.
2. Ensure correct orientation of the sockets; while they can physically fit in either direction, the bottom case cutouts are designed for the correct orientation only.
3. Test the soldered connection of each hotswap pad with a circuit tester using the 180-degree rotated direct solder holes. That's 72 tests, but very easy!

Good circuit-test of hotswap
Failing circuit-test of hotswap

## Pi Pico Installation

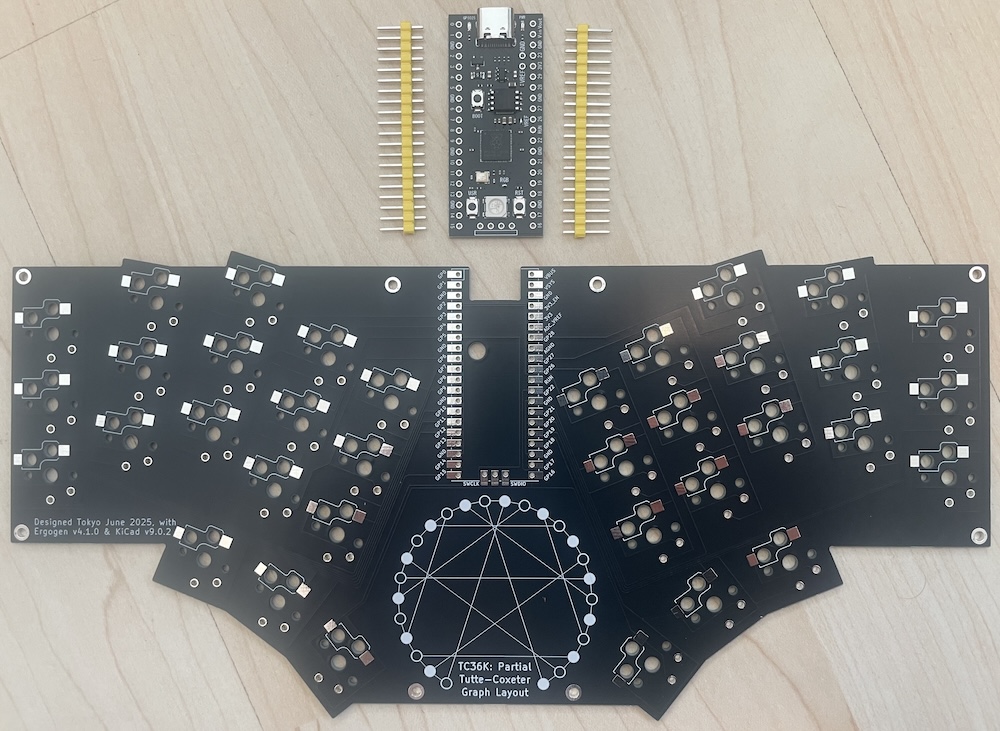
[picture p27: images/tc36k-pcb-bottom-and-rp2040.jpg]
DOWN side of PCB (with hotswap pads) with Raspberry Pi Pico face up, and header pins

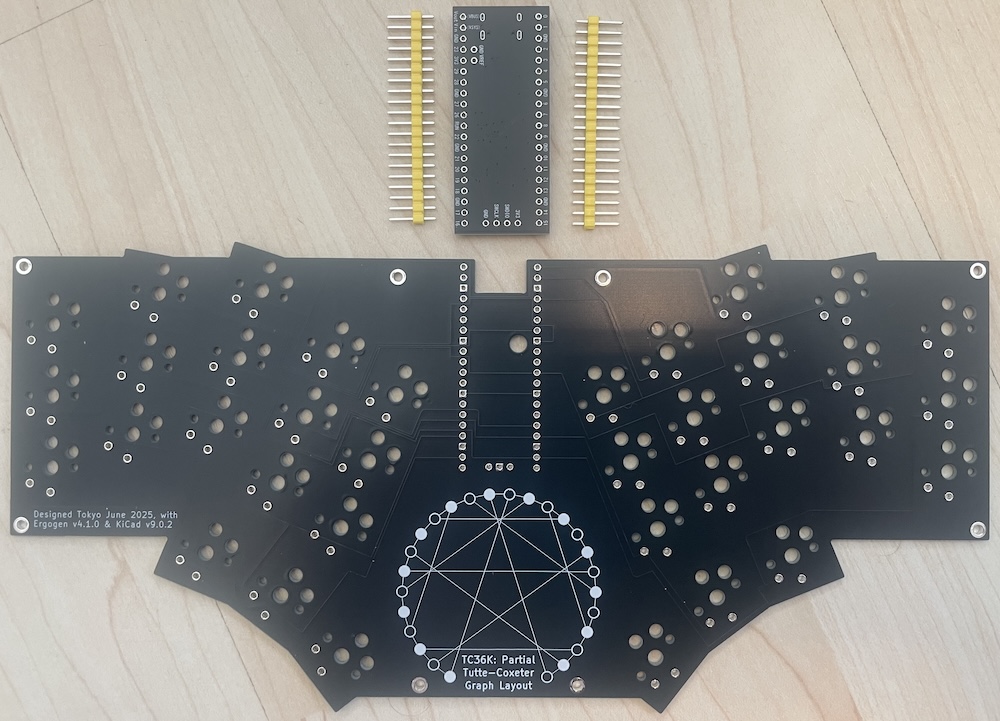
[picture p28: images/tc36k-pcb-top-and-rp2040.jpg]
UP side of PCB with Raspberry Pi Pico face down, and header pins


1. Install the Pi Pico on the UP side of the PCB (opposite from where hotswap sockets were installed).
2. Position the Pi Pico with its components facing down toward the PCB and the USB port facing outward.
3. Use the two 2.54mm × 20-pin headers provided (with ~2.5mm height insulators) to solder the Pi Pico onto the PCB. I had the short legs on the hotswap side as clearance is tightest with the bottom case (see below). We do not use the three pins opposite the USB port.
4. After soldering, carefully trim all protruding pins with a nipper.

*Your PCB should look like this when completed (hopefully with neater soldering):*

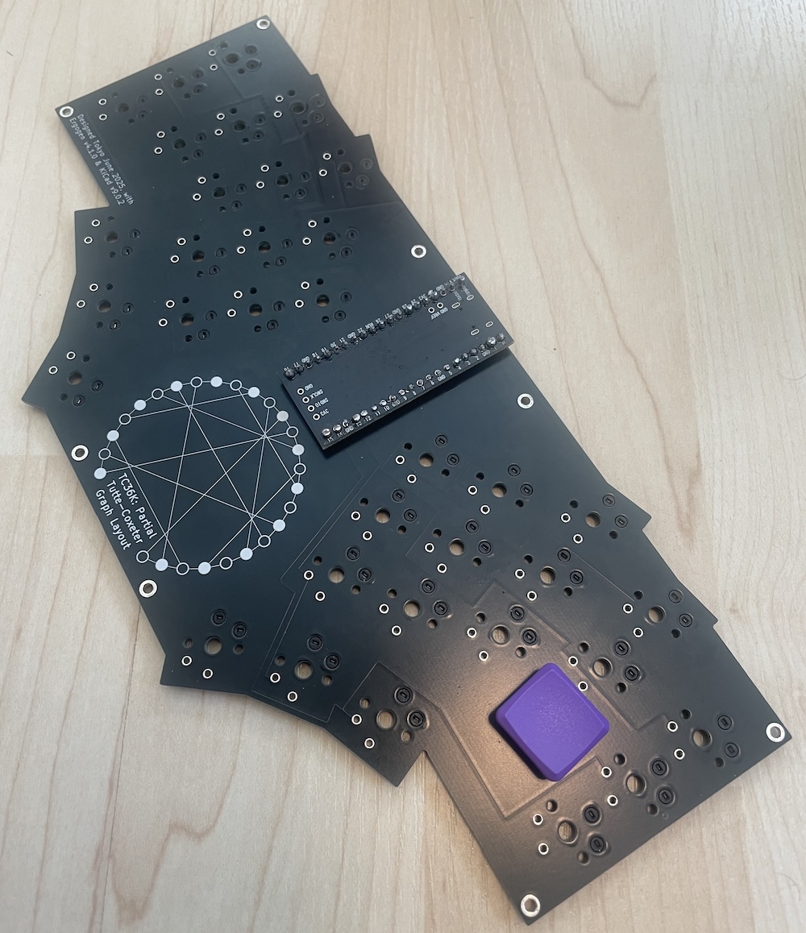
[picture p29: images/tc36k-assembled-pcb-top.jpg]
Top side of assembled Gamma-Omega TC36k PCB with face-down RP2040 controller

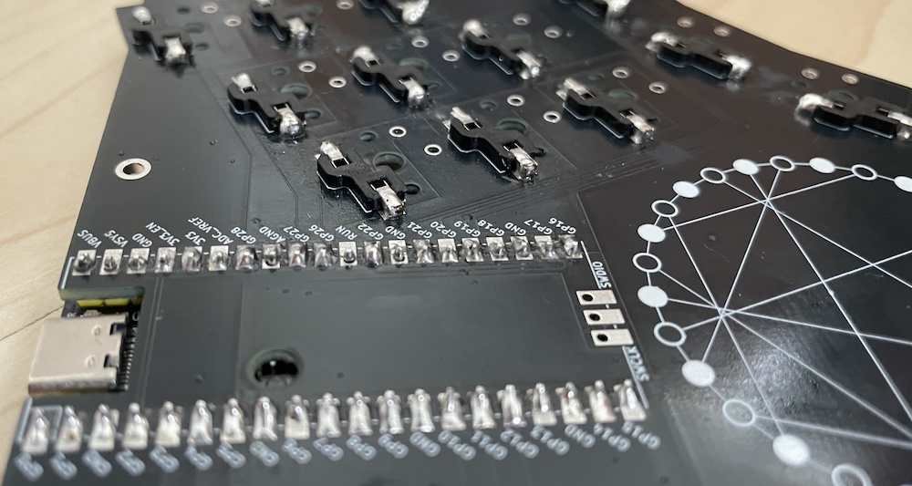
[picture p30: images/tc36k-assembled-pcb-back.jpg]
Bottom side of assembled Gamma-Omega TC36k PCB with hotswap sockets

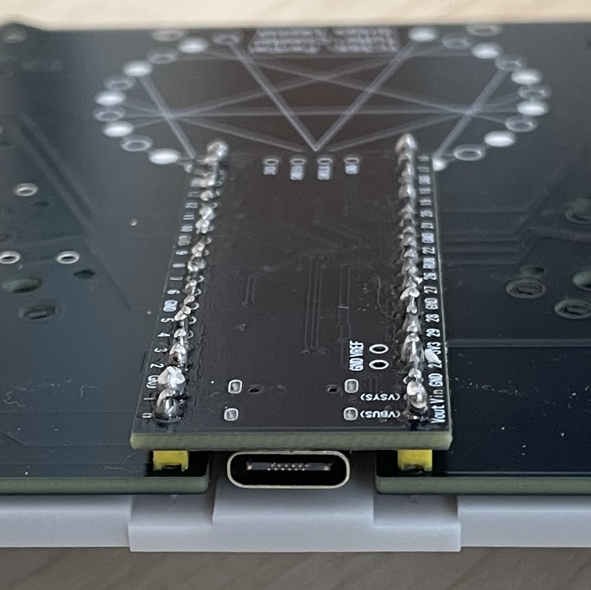
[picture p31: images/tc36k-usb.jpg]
Side view of assembled Gamma-Omega TC36k PCB on bottom case showing USB-C port


> [!CAUTION]
> For your safety, please wear safety glasses — trimmed pins can be sharp and may fly off during cutting.

## Testing
Connect the USB-C port on the assembled PCB, and it should still register as a keyboard.
The red power LED should light up (somewhat hidden).

As in the firmware notes above, press Caps Lock on your main keyboard and confirm the
blue LED lights up (again, somewhat hidden).

Use your favorite keystroke tester with a conductive tweezer to verify that all keys are working properly.

## Case Assembly
Install the nuts

1. Install 6mm threaded inserts with epoxy adhesive on the top case (upper side, near the USB port hole).
2. Install 2mm threaded inserts with epoxy adhesive on the top case (lower side, opposite the USB port hole).

> [!TIP]
> You may not need the glue, mine seems fine with friction alone.

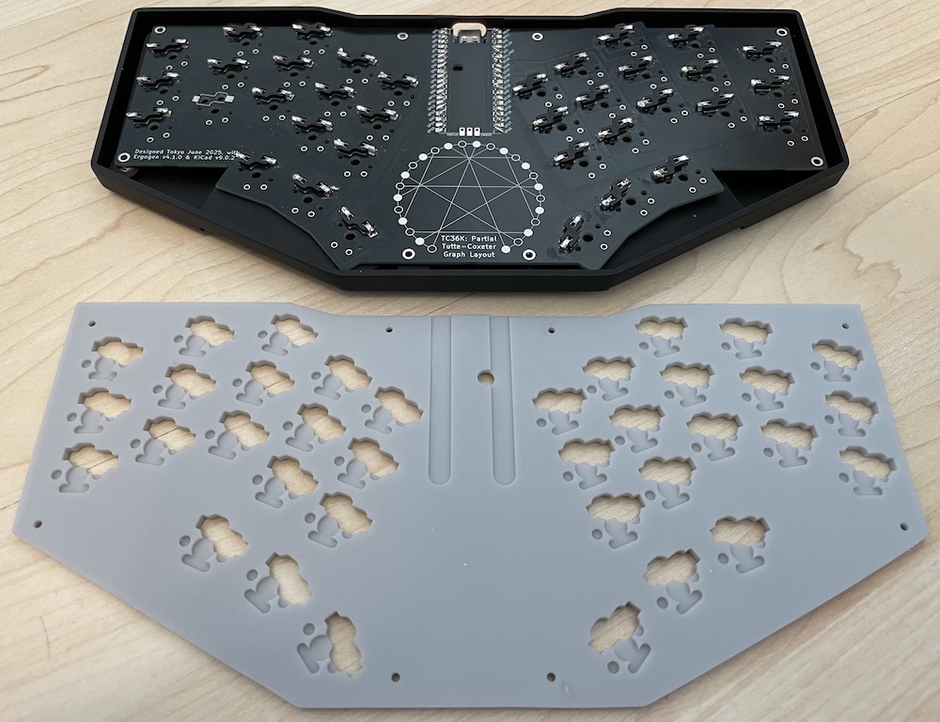
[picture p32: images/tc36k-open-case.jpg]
PCB placed inside the top case


3. Place the PCB onto the top case.
4. Install switches into the top case while holding the PCB (hotswap sockets) in place.

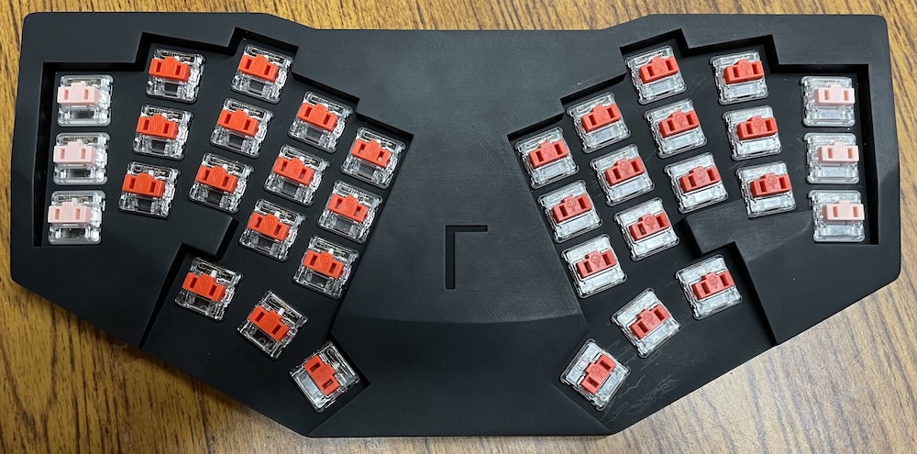
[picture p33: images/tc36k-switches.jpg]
Switches installed, red pros with pink on the pinkie columns


Top case and PCB held together by the switches, ready for bottom case to be screwed in

5. Place the bottom case onto the top case assembly.
6. Secure with screws (8mm or 6mm for upper side, 6mm for lower side).

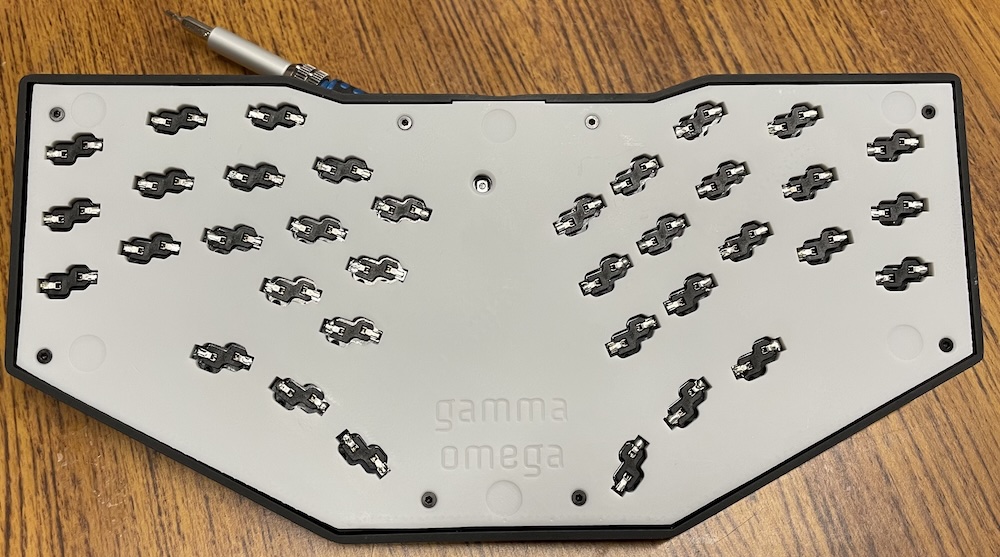
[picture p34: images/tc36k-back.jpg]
Bottom case screwed in (grey resin)


> [!TIP]
> Do not over-tighten: the screws should only need to support the bottom case's weight.

> [!CAUTION]
> My top case had warped ever so slightly, meaning the switches and outer screws are also bending it straight.

## DONE!

My assembled Gamma Omega TC36K, black resin top case with purple MBK keycaps
(black for the homing keys), and a grey resin bottom case underneath, and a
matching purple corded USB cable.

Assembled Gamma Omega TC36K keyboard in black and purple

Both the power (red) and caps-lock (blue) LEDs can be seen by the USB port, but are quite discrete.

### Everything is done.

How does it feel? Comfortable? Any issues? Does it work as you expected?

Whatever the result, we’d really appreciate it if you shared your experience with the community.

Thank you for building it!

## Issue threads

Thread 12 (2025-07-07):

Insert nut clarification

peterjc, 2025-07-07:
The build guide says:

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

Are those outer diameters for the nuts, i.e. M2 (OD 3MM), length 2MM or 6MM, sometimes listed as M2x2x3 and M2x6x3 respectively. So possibly https://www.aliexpress.com/item/1005008666672949.html or https://www.aliexpress.com/item/1005008239545159.html would work?

Do you happen to have any spares that could be photographed, or a suggested supplier?

unspecworks, 2025-07-07:
Yes, it's a nut with an outer diameter of 3mm. Whether or not the outer surface has knurling doesn't matter much in this case. Since the case is made of sla resin, we have no choice but to use adhesive anyway.

The hole in the case is drawn to 3mm, so as long as the nut's outer diameter is 3mm, it should tight perfect fit. However, keep in mind that there can be slight variations due to shrinkage depending on the material of the case.
Still, to ensure proper retention, a reasonably tight fit is desirable; and with adhesive, it should generally work fine.

what i used:

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

Closed 2025-07-28.

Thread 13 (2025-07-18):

Thoughts on using the LED (GP25) or WS2812 RGB (GP23) on the suggested controller

peterjc, 2025-07-18:
The [suggested controller](https://a.aliexpress.com/_opuRQZl) has an LED (GP25) and WS2812 RGB (GP23):

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

The current case design leaves the LED (GP25) and power LED potentially visible next to the USB port, while the RGB LED is face down between the controller and the plane of the main PCB in the middle of the case.

Potentially they might all be visible with a little light guide (clear plastic)... or an alternative clear acrylic case design.

unspecworks, 2025-07-18:
Yeah I thought about that too, but first of all GP23 is already in use so I don't know if it's possible, GP25 might be.

unspecworks, 2025-07-19:
Love these blue light. maybe enabling it by default.

unspecworks, 2025-08-21:
closed by 16aa84c

peterjc, 2025-08-21:
I did this in the TC36K firmware as https://github.com/peterjc/qmk_userspace/pull/6 (in C code) and then https://github.com/peterjc/qmk_userspace/pull/8 (in QMK JSON).

I did take some photos showing the blue caps lock and red power LED on, and shining out at the USB port casting some light on the desk and cable. Unless the whole room is dark, the effect is subtle and I didn't find it distracting. Rather it is there if I look for it:

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

Having the blue Caps Lock LED is a surprisingly useful quick-and-easy diagnostic that the keyboard is connected and the firmware running (especially when reflashing). I have since been working on a ZMK firmware for the TC36K board where this functionality isn't yet built in (the HID indicator status is tracked, and there are some community add-ons for controlling simple LEDs, so it can be done).

[I'm wondering about making a wireless Bluetooth version of the keyboard, which probably means ZMK rather than QMK as that has a very narrow set of supported BlueTooth hardware. The downside is the RP2040 controllers are comparitively battery hungry, and ZMK doesn't yet support their radio module, so this would likely mean switching to a different controller architecture - but hopefully a similar physcial footprint. The TC36K PCB could be shrunk to leave space for the battery where the current Tutte-Coxeter graph silk screen art is between the thumb keys & controller.]

unspecworks, 2025-08-21:
Maybe [this controller](https://circuitpython.org/board/makerdiary_nrf52840_connectkit/) has same form factor? so drop in replacement.

Closed 2025-08-21.

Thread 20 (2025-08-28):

Suggestion: Bluetooth variant

peterjc, 2025-08-28:
Currently the Raspberry Pi BlueTooth controllers are not supported by ZMK, and would likely be battery hungry anyway. I'm instead working on an [alternative PCB using the Supermini NRF52840](https://github.com/peterjc/gamma-omega/tree/supermini_nrf52840) (or perhaps the Nice!Nano v2) for bluetooth, since this is widely used with ZMK and has BlueTooth and battery charging built in. It does have less GPIO pins, which would mean the Graph Theory approach demonstrated in the TC36K PCB would be limited to only 4-key rollover this time (using the [Hesse Configuration Incidence Graph](https://houseofgraphs.org/graphs/44164) here, rather than the Tutte-Coxeter Graph were we get 6-key roll over).

This will need modest case changes - this is KiCad with a image of the top case exported from FreeCAD:

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

(1) Move the cross piece to make a battery compartment, eg this shows a 15x35mm cut-out for a 3.7v 110mAh 301230 battery. They may need a notch for the battery wires. I don't think the bottom case would also need thining there, but might for a larger battery.

(2) Move the USB cutout vertically up about 1mm. This controller has a mid-mounted USB port, and I am thinking to mount the controller face up directly on the PCB (castellated style).

(3) There will need to be a reset button on the PCB, possibly accessed by a hole in the back using a [reverse mounted button](https://thepihut.com/products/reverse-mount-tactile-switch-buttons-6mm-square-10-pack)? There should be room right next to the controller which is narrower than the Pico. Or a hole in the top and a tall button like the 6mm ones [here](https://thepihut.com/products/black-soft-caps-for-tactile-buttons-1-pack).

(4?) Possibly add small holes in top case above the controller's two LEDs (which I plan to have face up), ideally with a clear plastic light guide (see eg the light guides in the [Forager keyboard](https://github.com/carrefinho/forager/blob/main/docs/build-guide.md)).

(5?) Possibly the bottom case will also need minor changes for the controller pin rows being closer together.

(6?) Add thin "skin" to bottom case covering the hotswaps?

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

I don't see an _easy_ way to add a physical power switch. Perhaps the top edge near the USB port, or a push switch? Instead maybe just use [ZMK soft-off](https://zmk.dev/docs/features/low-power-states#soft-off)?

Q: Do these case ideas seem realistic [I will have a go myself]?

Q: Are you happy in principle to have this in the Gamma Omega family?

unspecworks, 2025-08-28:
This is certainly a very bold variant. At this point, as long as the layout and overall case shape are preserved, the Gamma Omega name could be retained.

Here are my thoughts:

1
With only minor adjustments to the beams and the lower case design, it should be possible to create sufficient space for the battery.  Personally, I would recommend adding a connector (JST, Molex), pads, or THT options near the battery for ease of connection.
(This may, of course, depend on whether a physical power switch is implemented.)

3
 If you are planning to use ZMK (not ZMK Studio, or RMK’s Vial features), resetting will likely be frequent, so accessibility will be important.  Due to thick case walls and space limitations, a side-mounted button does not seem feasible.

Suggestion: place a small SMT reset button between the key switches.   This would make it easy to press with something always at hand(like a pen) without needing to flip the board over or find a small hole.

4
It may be rather difficult to source a light guide diffuser thing that fits precisely for the LEDs.

6
Originally, the bottom case was exposed in a TOTEM-like style to maintain a slim profile.  However, since resin printing is being considered for case production, the thickness has increased. Thus, there is no longer a functional reason to keep the hotswap sockets exposed, but it was retained for aesthetic reasons.  With the current thickness, there should be sufficient clearance. GTG!

A physical power switch still seems quite difficult to implement given the limited space.
Instead, it may be better to rely on ZMK’s soft-off feature and ensure the reset button is more accessible so it can effectively double as a power switch.
This concept is somewhat similar to the [new project](https://github.com/carrefinho/visorbearer) by the creator of the Forager keyboard. worth taking a look.

Additionally, note that the extra pin layouts differ between the Supermini nRF52840 and the Nice!Nano v2, so please keep that in mind.

peterjc, 2025-08-28:
1. Good - I was hoping you'd agree moving the beams was realistic. Given how short the leads seem to be on most/all of the batteries, direct wiring would need an extension anyway. A connector is also more attractive if I skip a power switch.
2. Moving the USB hole up 1mm should be easy...
3. I have got ZMK Studio working on the TC36K, so should be able to use that here too - but I agree it isn't yet as capable as QMK/Vial. RMK could work too 😄 - I will ponder the reset button placement, next to the top row ring finger is intriging.
4. I will probaly skip the LED light guide for a first attempt.
5. Moving the controller pin cut-out should be easy...
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
unspecworks, 2025-09-16:
Yeah, that’s right. If I’m not using a Pico, then with a ProMicro-like controller it feels like going wireless might actually make more sense.

I never really worried within 6key rollover, but with only 4-key rollover.. I guess I’d have to think more carefully about the layout. That’s something I’ll need to spend more time on. Maybe there are also some firmware-side improvements to explore (though with ZMK that could be tricky).

peterjc, 2025-09-19:
This issue has turned into a build diary 😅

After shorting reset to ground a few times, it kept flashing blue, but appeared as a `NICENANO` USB storage device. File `INFO_UF2.TXT` had:

```
UF2 Bootloader 0.6.0 lib/nrfx (v2.0.0) lib/tinyusb (0.10.1-41-gdf0cda2d) lib/uf2 (remotes/origin/configupdate-9-gadbb8c7)
Model: nice!nano
Board-ID: nRF52840-nicenano
SoftDevice: S140 version 6.1.1
Date: Jun 19 2021
```

I took a copy of this and the firmware.

I tried copying over my `hesse-nice_nano_v2-zmk.uf2` file, got an error:

`The Finder can't complele the operation because some data in "hesse-nice_nano_v2-zmk.uf2" can't be read or written. (Error code -36)`

There was also the usual notification about not ejecting the drive, and the blue LED kept flashing. However, `system_profiler SPUSBDataType` then gave:

```
            Hesse:

              Product ID: 0x615e
              Vendor ID: 0x1d50
              Version: 3.05
              Serial Number: EC8516EEC837290C
              Speed: Up to 12 Mb/s
              Manufacturer: ZMK Project
              Location ID: 0x03110000 / 3
              Current Available (mA): 500
              Current Required (mA): 100
              Extra Operating Current (mA): 0
```

It was not recognized as a keyboard in Karabiner Elements or with a macOS promt to configure it. I unplugged it, and plugged it in again. No change.  I did the reset & retried flashing, twice, same. The firmware is a little larger than I expected at 479kb, but that doesn't seem unusally large for a Bluetooth ZMK.

I had taken a copy of the 1s flashing default firmware, so put that back. Same error message, but it seems to have worked 🤷

Looks like my firmware did not work first time. I'll check for a promicro ZMK test firmware next I think.

peterjc, 2025-09-19:
OK, it _was_ working but Bluetooth only? It occured to me USB support might be off by default, and it apparently is 😆

I connected my phone to the "Hesse" on Bluetooth, and shorted a row/col pair of pins. Nothing happened on the phone, but the expected letters appeared on the computer (!). I assume some Apple magic there.

And "Hesse" appears on the Mac's Bluetooth add keyboard, but does not seem to want to connect:

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

And now the phone won't reconnect (tried unplugging the Supermini and restarting it). 🤷

And during all of that, it still flashes the blue LED non-stop 😱

peterjc, 2025-09-20:
I have concluded that Karabiner Elements is confused by two keyboards with the same USB IDs (even with different names and serial numbers), so it was only showing my Gamma Omega TC36K last night. Today it is preferring to show the Hesse.

I have fixed some typos and off by one errors in the pins and matrix, and now in USB mode with shorting two pins at a time all the keys seem to work (layer key not tested).

The blue LED _may_ be the power LED (some of these had the red/blue swapped), and if so this means no battery attached.

Bluetooth testing pending...

peterjc, 2025-09-24:
No need to change the top case for the USB based on putting together the old case, an empty TC36K PCB, and the supermini in situ:

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

peterjc, 2025-09-24:
Comparing the reset switch to the screw point it will be next to, there is enough vertical height (just), but I plan a slight thinning of the case anyway.

peterjc, 2025-09-24:
There is enough vertical height for the reset switch but a little case thinning there won’t hurt:

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

peterjc, 2025-09-24:
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

Last set of photos, this is my new LP602030 battery in the original Gamma Omega top case for a sense of scale (it will be further down and rotated), and showing without a PCB cutout the nominal 6mm thickness battery fits but would be very snug.

Closed 2025-10-07.

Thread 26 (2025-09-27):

Request for a choc v2 tc36k pcb

Celepara, 2025-09-27:
If possible to add a choc v2 compatible pcb for the tc36k version ready to be sent out to be ordered!

peterjc, 2025-09-30:
I had my head in another project this morning, but hopefully tonight...

peterjc, 2025-09-30:
Clean version coming up shortly. Tiny ergogen change:

```
-          choc_v2_support: false
+          choc_v2_support: true
+          include_stabilizer_pad: false
```

Then a bunch of PCB diffs like this (can apply this on top of the existing KiCad file with the traces etc using `sed`):

```
<     (pad "" np_thru_hole circle (at 0 0 52) (size 3.4 3.4) (drill 3.4) (layers "*.Cu" "*.Mask"))
---
>     (pad "" np_thru_hole circle (at 0 0 52) (size 5 5) (drill 5) (layers "*.Cu" "*.Mask"))
```

Then some manual work (text on the silkscreen, gerbers).

peterjc, 2025-09-30:
I am working on this at https://github.com/peterjc/gamma-omega/tree/tc36k_v1_1_0 - I couldn't resist the chance to shorten some of the traces with a few more diagonals rather than 90 degree corners, so adjusting the traces to go round the larger centre holes took longer than I expected. 😅

Getting there!

peterjc, 2025-09-30:
There's something about this Tutte-Coxeter wiring that makes passing the ground plane checks surprisingly hard - what I'd love is a KiCad option to color the ground plane by distance to nearest GND pin (like a rainbow) to flag the electrcally furthest corners. Anyway, got there.

Celepara, 2025-10-07:
I will be ordering the pcbs very soon! Probably will have something built
within 2-3 weeks!

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

Closed 2025-10-01.

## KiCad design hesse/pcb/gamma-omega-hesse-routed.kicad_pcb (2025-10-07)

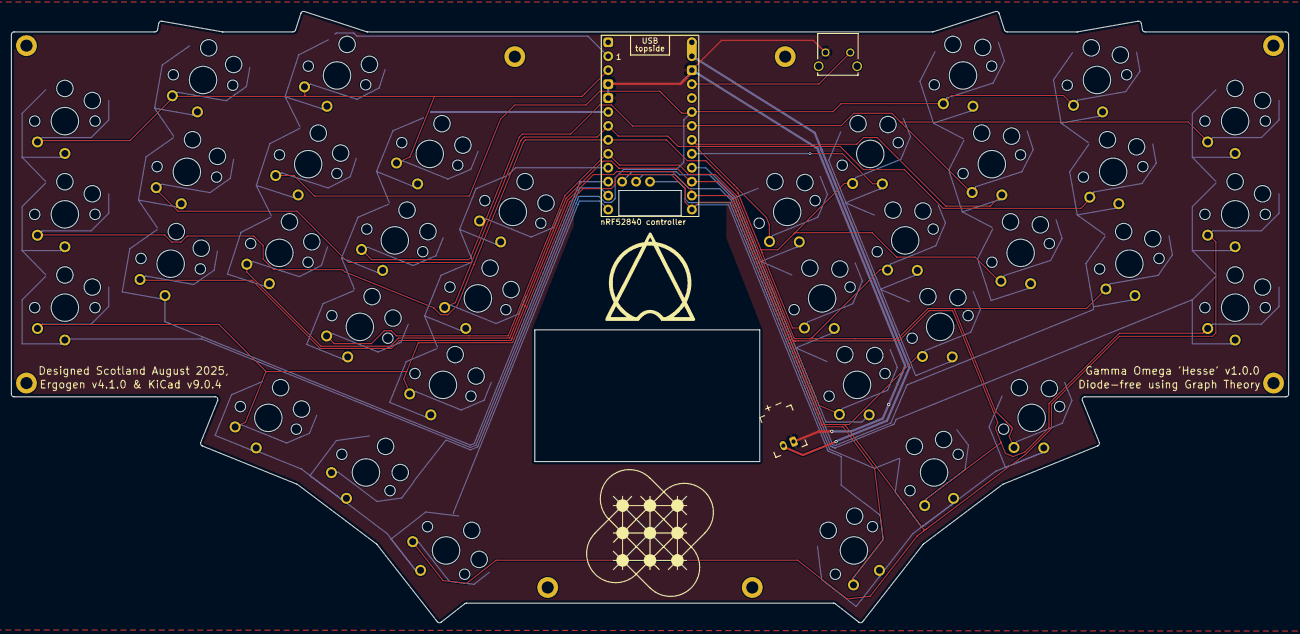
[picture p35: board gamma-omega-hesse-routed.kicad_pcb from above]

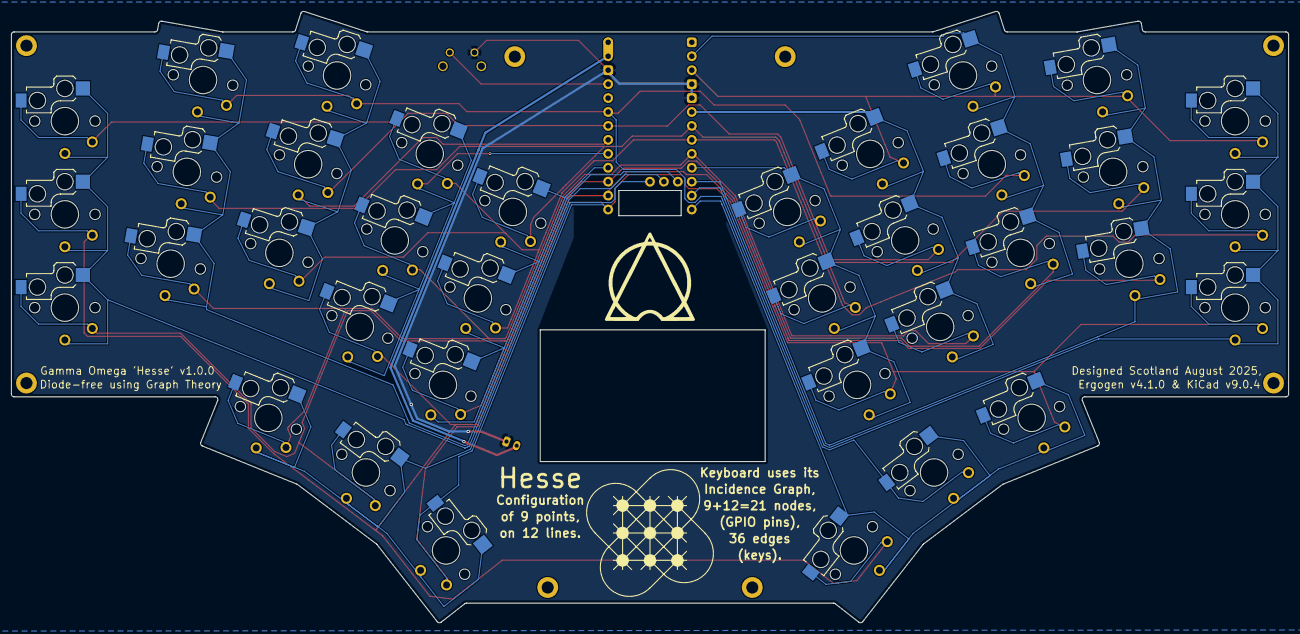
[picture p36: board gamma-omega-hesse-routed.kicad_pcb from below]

Board: 2 copper layers, 232.8 x 111.4 mm, 47 parts (36 on the bottom side), 24 nets.

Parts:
 nRF52840 controller: nice_nano_AH_USBup
H1, H2, H3, H4, H5, H6, H7, H8: mounting_hole_plated
JST1: battery_connector_jst_ph_2
RST1: reset_switch_1825027-8
S1, S2, S3, S4, S5, S6, S7, S8, S9, S10, S11, S12, S13, S14, S15, S16, S17, S18, S19, S20, S21, S22, S23, S24, S25, S26, S27, S28, S29, S30, S31, S32, S33, S34, S35, S36: switch_choc_v1_v2

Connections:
C1: nRF52840 controller.11, S1.1, S1.2, S2.1, S2.2, S3.1, S3.2
C2: nRF52840 controller.10, S4.1, S4.2, S5.1, S5.2, S6.1, S6.2
C3: nRF52840 controller.1, S7.1, S7.2, S8.1, S8.2, S9.1, S9.2
C4: nRF52840 controller.5, S10.1, S10.2, S11.1, S11.2, S12.1, S12.2
C5: nRF52840 controller.9, S13.1, S13.2, S14.1, S14.2, S15.1, S15.2
C6: nRF52840 controller.12, S16.1, S16.2, S17.1, S17.2, S18.1, S18.2
C7: nRF52840 controller.27, S34.1, S34.2, S35.1, S35.2, S36.1, S36.2
C8: nRF52840 controller.21, S31.1, S31.2, S32.1, S32.2, S33.1, S33.2
C9: nRF52840 controller.20, S28.1, S28.2, S29.1, S29.2, S30.1, S30.2
C10: nRF52840 controller.19, S25.1, S25.2, S26.1, S26.2, S27.1, S27.2
C11: nRF52840 controller.25, S22.1, S22.2, S23.1, S23.2, S24.1, S24.2
C12: nRF52840 controller.26, S19.1, S19.2, S20.1, S20.2, S21.1, S21.2
GND: nRF52840 controller.3, nRF52840 controller.4, nRF52840 controller.14, JST1.1, RST1.2
R1: nRF52840 controller.2, S3.1, S3.2, S6.1, S6.2, S9.1, S9.2, S12.1, S12.2
R2: nRF52840 controller.24, S1.1, S1.2, S13.1, S13.2, S16.1, S16.2, S36.1, S36.2
R3: nRF52840 controller.7, S2.1, S2.2, S25.1, S25.2, S30.1, S30.2, S32.1, S32.2
R4: nRF52840 controller.6, S5.1, S5.2, S14.1, S14.2, S23.1, S23.2, S33.1, S33.2
R5: nRF52840 controller.23, S4.1, S4.2, S18.1, S18.2, S20.1, S20.2, S28.1, S28.2
R6: nRF52840 controller.22, S7.1, S7.2, S19.1, S19.2, S31.1, S31.2, S35.1, S35.2
R7: nRF52840 controller.17, S8.1, S8.2, S17.1, S17.2, S24.1, S24.2, S27.1, S27.2
R8: nRF52840 controller.8, S10.1, S10.2, S22.1, S22.2, S29.1, S29.2, S34.1, S34.2
R9: nRF52840 controller.18, S11.1, S11.2, S15.1, S15.2, S21.1, S21.2, S26.1, S26.2
RAW: nRF52840 controller.13, nRF52840 controller.29, JST1.2
RST: nRF52840 controller.15, RST1.1

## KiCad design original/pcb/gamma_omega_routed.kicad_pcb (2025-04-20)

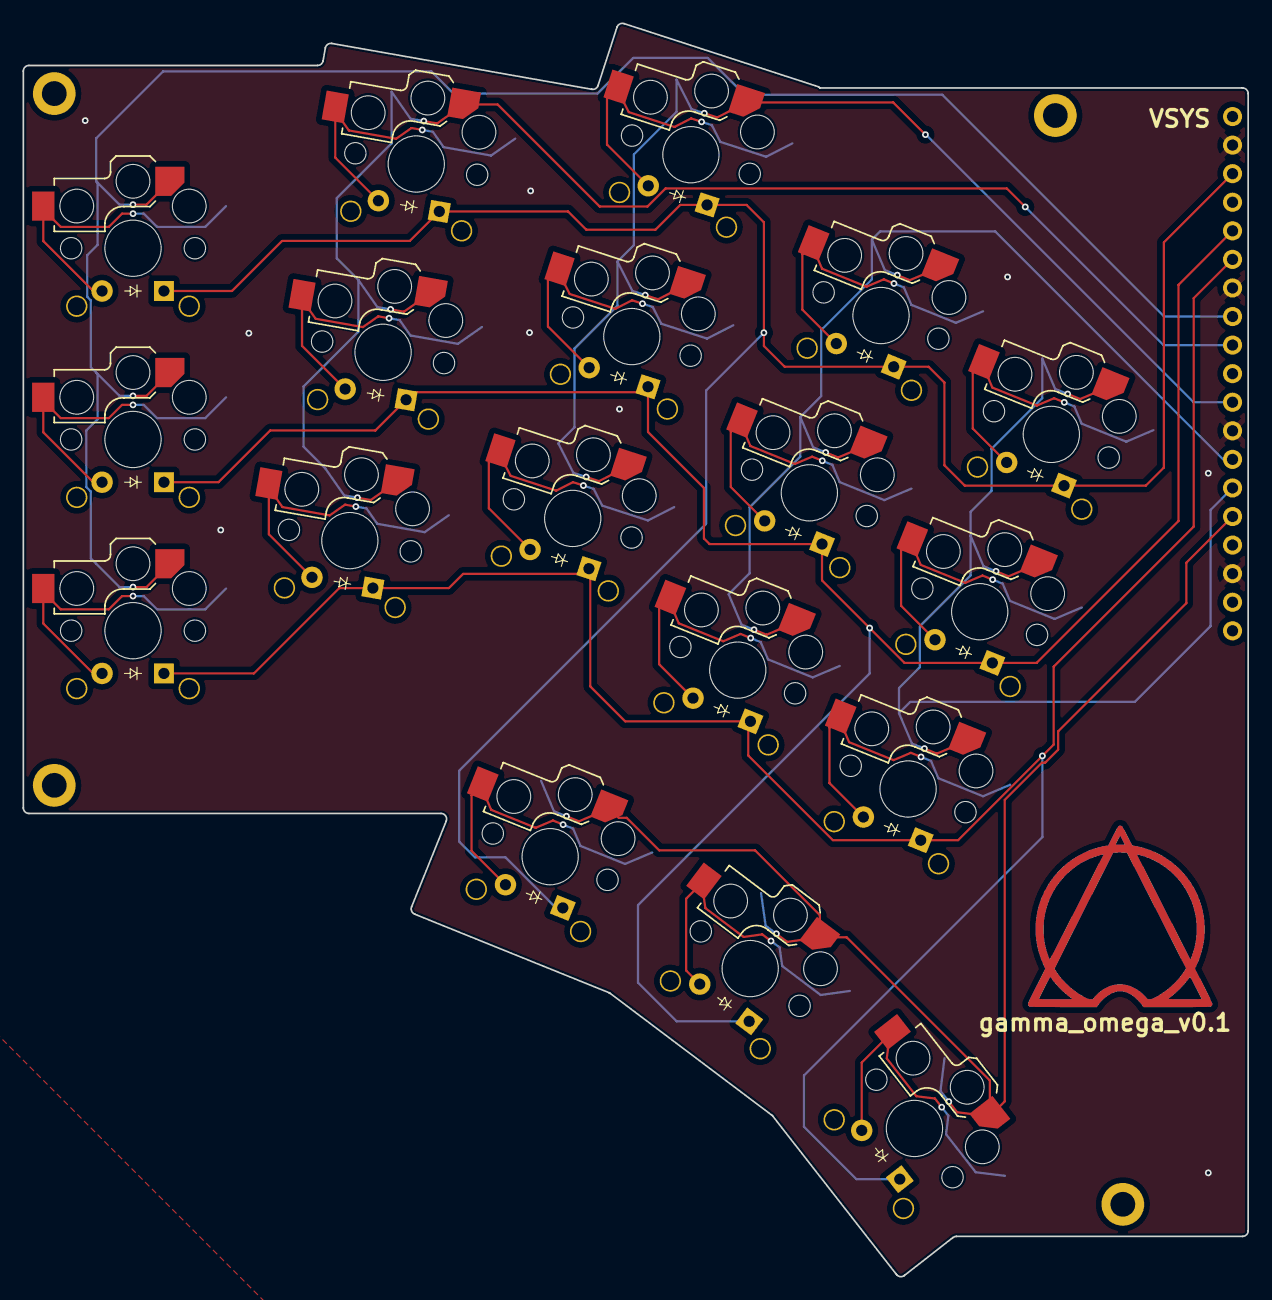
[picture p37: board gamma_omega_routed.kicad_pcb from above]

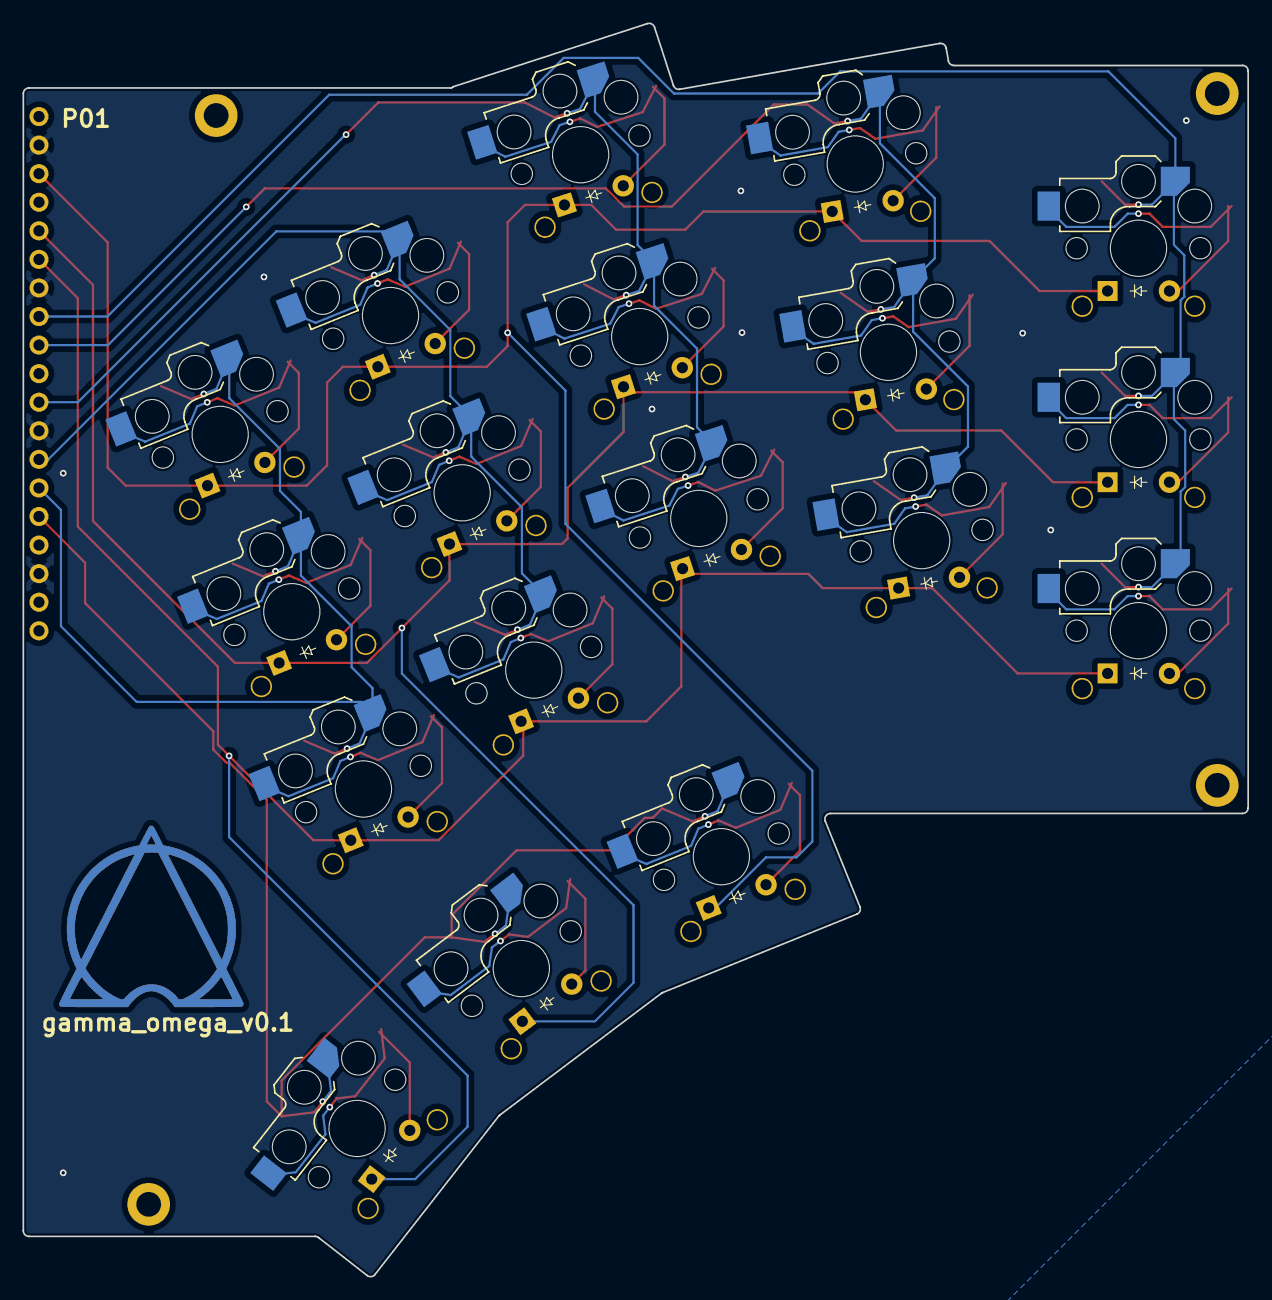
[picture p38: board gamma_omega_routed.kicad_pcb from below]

Board: 2 copper layers, 108.9 x 111.4 mm, 41 parts (18 on the bottom side), 28 nets.

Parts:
D1, D2, D3, D4, D5, D6, D7, D8, D9, D10, D11, D12, D13, D14, D15, D16, D17, D18: diode_tht_sod123
H1, H2, H3, H4: mounting_hole_plated
MCU1: nice_nano
S1, S2, S3, S4, S5, S6, S7, S8, S9, S10, S11, S12, S13, S14, S15, S16, S17, S18: switch_choc_v1_v2

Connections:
C0: MCU1.9, S1.1, S2.1, S3.1
C1: MCU1.10, S4.1, S5.1, S6.1
C2: MCU1.12, S7.1, S8.1, S9.1
C3: MCU1.14, S10.1, S11.1, S12.1
C4: MCU1.15, S13.1, S14.1, S15.1
C5: MCU1.16, S16.1, S17.1, S18.1
GND: MCU1.3, MCU1.8, MCU1.13, MCU1.18
R0: D3.1, D6.1, D9.1, D12.1, D15.1, D16.1, MCU1.4
R1: D2.1, D5.1, D8.1, D11.1, D14.1, D17.1, MCU1.6
R2: D1.1, D4.1, D7.1, D10.1, D13.1, D18.1, MCU1.7
S1: D3.2, S3.2
S2: D2.2, S2.2
S3: D1.2, S1.2
S4: D6.2, S6.2
S5: D5.2, S5.2
S6: D4.2, S4.2
S7: D9.2, S9.2
S8: D8.2, S8.2
S9: D7.2, S7.2
S10: D12.2, S12.2
S11: D11.2, S11.2
S12: D10.2, S10.2
S13: D15.2, S15.2
S14: D14.2, S14.2
S15: D13.2, S13.2
S16: D16.2, S16.2
S17: D17.2, S17.2
S18: D18.2, S18.2

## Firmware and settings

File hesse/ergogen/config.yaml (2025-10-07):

meta:
  engine: 4.1.0
units:
  cx: 17.5
  cy: 16.5
  mg: 50
points:
  mirror:
    ref: matrix_inner_top
    distance: mg
  zones:
    matrix:
      anchor.shift: [50,-100] # Fix KiCad placement
      columns:
        pinky:
          key:
            spread: 12
            splay: 0
            origin: [0, -10]
            width: cx
            height: cy
          rows:
            bottom:
              bind: [0, 30, 7, 0]
              column_net: C1
              row_net: R2
              mirror.column_net: C12
              mirror.row_net: R6
            home:
              bind: [0, 0, 0, 0]
              column_net: C1
              row_net: R3
              mirror.column_net: C12
              mirror.row_net: R5
            top:
              bind: [7, 15, 20, 0]
              column_net: C1
              row_net: R1
              mirror.column_net: C12
              mirror.row_net: R9
        ring:
          key:
            spread: cx - 1
            stagger: cy * 0.5
            splay: -10
            origin: [0, -16]
            width: cx
            height: cy
          rows:
            bottom:
              bind: [0, 0, 0, 0]
              column_net: C2
              row_net: R5
              mirror.column_net: C11
              mirror.row_net: R8
            home:
              bind: [0, 0, 0, 0]
              column_net: C2
              row_net: R4
              mirror.column_net: C11
              mirror.row_net: R4
            top:
              bind: [0, 10, 20, 0]
              column_net: C2
              row_net: R1
              mirror.column_net: C11
              mirror.row_net: R7
        middle:
          key:
            shift: [0, 0]
            spread: cx 
            stagger: cy/3
            splay: -8
            origin: [0, -12]
            width: cx
            height: cy
          rows:
            bottom:
              bind: [0, 0, 0, 0]
              column_net: C3
              row_net: R6
              mirror.column_net: C10
              mirror.row_net: R3
            home:
              bind: [0, 0, 0, 0]
              column_net: C3
              row_net: R7
              mirror.column_net: C10
              mirror.row_net: R9
            top:
              bind: [0, 0, 0, 0]
              column_net: C3
              row_net: R1
              mirror.column_net: C10
              mirror.row_net: R7
        index:
          key:
            spread: cx - .6
            stagger: -cy/2
            splay: -4
            origin: [0, -cx]
            width: cx
            height: cy
          rows:
            bottom:
              bind: [0, 0, 0, 0]
              column_net: C4
              row_net: R8
              mirror.column_net: C9
              mirror.row_net: R5
            home:
              bind: [0, 0, 0, 0]
              column_net: C4
              row_net: R9
              mirror.column_net: C9
              mirror.row_net: R8
            top:
              bind: [0, 0, 10, 10]
              column_net: C4
              row_net: R1
              mirror.column_net: C9
              mirror.row_net: R3
        inner:
          key:
            spread: cx+.5
            stagger: -cy/4
            splay: 0
            origin: [0, -cy]
            width: cx
            height: cy
          rows: 
            bottom:
              bind: [0, 0, 0, 0]
              column_net: C5
              row_net: R2
              mirror.column_net: C8
              mirror.row_net: R6
            home:
              bind: [0, 0, 0, 0]
              column_net: C5
              row_net: R4
              mirror.column_net: C8
              mirror.row_net: R3
            top:
              bind: [0, 40, 40, 0]
              column_net: C5
              row_net: R9
              mirror.column_net: C8
              mirror.row_net: R4
      rows:
        bottom:
          padding: cy + .5
        home:
          padding: cy + .5
        top:
    thumb:
      anchor:
        ref: matrix_inner_bottom
        shift: [-cx * 1.5 - 1,-cy-1]
      columns:
        first:
          key:
            splay: 0
            width: cx
            height: cy
          rows:
            only:
              column_net: C6
              row_net: R2
              mirror.column_net: C7
              mirror.row_net: R8
              bind: [15, 5, 0, 0]
        second:
          key:
            spread: cx + .75
            splay: -15
            origin: [-cx/2, -cx/2]
            width: cx
            height: cy
          rows:
            only:
              column_net: C6
              row_net: R7
              mirror.column_net: C7
              mirror.row_net: R6
              bind: [10, 5, 0, 5]
        third:
          key:
            spread: cx + .75
            splay: -15
            origin: [-cx/2, -cx/2]
            width: cx
            height: cy
          rows:
            only:
              column_net: C6
              row_net: R5
              mirror.column_net: C7
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

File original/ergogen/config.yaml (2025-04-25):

meta:
  engine: 4.1.0
units:
  cx: 17.5
  cy: 16.5
  mg: 50
points:
  # for debuging.
  # mirror:
  #   ref: matrix_inner_top
  #   distance: mg
  zones:
    matrix:
      anchor.shift: [50,-100] # Fix KiCad placement
      columns:
        pinky:
          key:
            spread: 12
            splay: 0
            origin: [0, -10]
            width: cx
            height: cy
          rows:
            bottom:
              bind: [0, 30, 7, 0]
              column_net: C0
              row_net: R2
              sw_net: S3
            home:
              bind: [0, 0, 0, 0]
              column_net: C0
              row_net: R1
              sw_net: S2
            top:
              bind: [7, 15, 20, 0]
              column_net: C0
              row_net: R0 
              sw_net: S1
        ring:
          key:
            spread: cx - 1
            stagger: cy * 0.5
            splay: -10
            origin: [0, -16]
            width: cx
            height: cy
          rows:
            bottom:
              bind: [0, 0, 0, 0]
              column_net: C1
              row_net: R2 
              sw_net: S6
            home:
              bind: [0, 0, 0, 0]
              column_net: C1
              row_net: R1
              sw_net: S5
            top:
              bind: [0, 10, 20, 0]
              column_net: C1
              row_net: R0
              sw_net: S4
        middle:
          key:
            shift: [0, 0]
            spread: cx 
            stagger: cy/3
            splay: -8
            origin: [0, -12]
            width: cx
            height: cy
          rows:
            bottom:
              bind: [0, 0, 0, 0]
              column_net: C2
              row_net: R2
              sw_net: S9
            home:
              bind: [0, 0, 0, 0]
              column_net: C2
              row_net: R1
              sw_net: S8
            top:
              bind: [0, 0, 0, 0]
              column_net: C2
              row_net: R0
              sw_net: S7
        index:
          key:
            spread: cx - .6
            stagger: -cy/2
            splay: -4
            origin: [0, -cx]
            width: cx
            height: cy
          rows:
            bottom:
              bind: [0, 0, 0, 0]
              column_net: C3
              row_net: R2
              sw_net: S12
            home:
              bind: [0, 0, 0, 0]
              column_net: C3
              row_net: R1
              sw_net: S11
            top:
              bind: [0, 0, 10, 10]
              column_net: C3
              row_net: R0
              sw_net: S10
        inner:
          key:
            spread: cx+.5
            stagger: -cy/4
            splay: 0
            origin: [0, -cy]
            width: cx
            height: cy
          rows: 
            bottom:
              bind: [0, 0, 0, 0]
              column_net: C4
              row_net: R2
              sw_net: S15
            home:
              bind: [0, 0, 0, 0]
              column_net: C4
              row_net: R1
              sw_net: S14
            top:
              bind: [0, 40, 40, 0]
              column_net: C4
              row_net: R0
              sw_net: S13
      rows:
        bottom:
          padding: cy + .5
        home:
          padding: cy + .5
        top:
    thumb:
      anchor:
        ref: matrix_inner_bottom
        shift: [-cx * 1.5 - 1,-cy-1]
      columns:
        first:
          key:
            splay: 0
            width: cx
            height: cy
          rows:
            only:
              column_net: C5
              row_net: R0
              sw_net: S16
              bind: [15, 5, 0, 0]
        second:
          key:
            spread: cx + .75
            splay: -15
            origin: [-cx/2, -cx/2]
            width: cx
            height: cy
          rows:
            only:
              column_net: C5
              row_net: R1
              sw_net: S17
              bind: [10, 5, 0, 5]
        third:
          key:
            spread: cx + .75
            splay: -15
            origin: [-cx/2, -cx/2]
            width: cx
            height: cy
          rows:
            only:
              column_net: C5
              row_net: R2
              sw_net: S18
              bind: [15, 0, 0, 0]
        # fourth:
        #   key:
        #     spread: cx + .5
        #     splay: 0
        #     origin: [-cx/2, -cx/2]
        #   rows:
        #     only:
        #       column_net: C2
        #       row_net: D0
        #       
outlines:
  raw:
    - what: rectangle
      where: true
      bound: true
      asym: both
      size: [cx, cy]
      corner: 0
  pcb:
    - what: outline
      name: raw
    - what: rectangle
      where: matrix_inner_top
      asym: source
      size: [100, 30]
      adjust:
        shift: [mg / 2, 14.8]
        orient: 22
      operation: add
    - what: rectangle #center bot
      where: matrix_inner_top
      asym: source
      size: [70, 29]
      adjust:
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

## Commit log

2025-04-20 first init
    [bottom.step, gamma_omega_routed.kicad_pcb, top.step]
2025-04-23 Improved top case model
    [top.step]
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2025-06-11 Document importance of boot button placement on RP2040 controller
    The PNG image was cropped from the Ali Express listing for the "black" board.
    The boot button circled in red.
    The "green" and "purple" boards on this listing have different button placement.
    The "Lite" versions too, plus they are narrower than the Pi Pico standard.
2025-06-11 Fix board alt-text
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2025-06-20 Starting work on a no-diode mono-PCB layout using Graph Theory
    See issue #1 and https://astrobeano.blogspot.com/2025/05/ergo-mech-keyboard-wiring-using-tutte-coxeter-graph.html
    The plan is to design an alternative larger single PCB compatible with the original Gamma-Omega case.
    This will use the same class of 26 GPIO microcontroller and a 26 of 30 vertex subset of the bipartite Tutte-Coxeter graph to control 36 keys (graph edges) within a sparse 13x13 virtual scanning matrix.
    [config.yaml]
2025-06-20 Rename board & make it into a mono PCB
    Following the advice given, uncomment the mirroring, and remove the
    block that subtracts edgecut.
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2025-06-20 Switch from half header to full Raspberry Pi Pico footprint.
    Using a footprint submitted to erogegen as pull request 144.
    Note: Will need to move the cutting edge up a couple of mm as
    I want to use GP zero (unused in split PCB design). There looks
    to be enough clearance with the original case design.
    This is setup with the hotswaps on the back (default) and
    controller also on the back (although it will actually be upside
    down on the front with header pins for spacing). i.e. once
    assembled the rp2040 will be face down, and the PCB front
    silkscreen will be visible along with the keycaps. The hotswap
    sockets and silkscreen art on the PCB back will face the table.
    [config.yaml]
2025-06-20 Make PCB taller in center to allow access to GPIO zero
    The original PCB didn't connect the top pair of pins, so was smaller.
    This makes all the top edge horizontal cuts at the same y-value,
    giving a tiny bit more room for traces above the middle & ring
    fingers.
    This should still fit comfortably in the original case design.
    [config.yaml]
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2025-06-20 Swapping pins for scanning rows 5 & 13 simpler to layout
    [config.yaml]
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2025-06-20 Reorder pins as per new sketch map
    Columns renumbered as per graph outer circle (thumbs now C9,C13,C11,
    left still C1,C2,C3,C4,C5, right now C6,C7,C8,C10,C12).
    Column traces stay on front of PCB plus thumbs for R7 & R13, and now
    also all of R7, more of R13, part of R1, and all of R3 & R5. This lets
    us avoid some of the biggest detours, and traces along the top edge.
    [config.yaml]
2025-06-20 Use shorter name in Ergogen for PCB
    [config.yaml]
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2025-06-25 Restructure folder hierarchy for TC36k variant support
    Separated original and TC36k variant into distinct folders to better reflect structural differences.
    Moved relevant files accordingly based on variant-specific requirements.
    Note: Commit history was not preserved during file moves. However, as there were no critical changes since the initial release, no further action was taken regarding commit retention.
    [gamma_omega_routed.kicad_pcb]
2025-06-26 Initial PCB from Ergogen v4.1.0, via KiCad v9.0.2
    ❯ ergogen tc36k/ergogen && cp output/pcbs/gamma-omega-tc36k.kicad_pcb tc36k/pcb/gamma-omega-tc36k-routed.kicad_pcb
    Ergogen v4.1.0 CLI
    Analyzing folder...
    Interpreting format: YAML
    Preprocessing input...
    Checking compatibility...
    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
    [gamma-omega-tc36k-routed.kicad_pcb]
2025-06-26 Add text to board silkscreen with date & tools
    [gamma-omega-tc36k-routed.kicad_pcb]
2025-06-26 Traces and ground plane in KiCad v9.0.2
    This was the result of a lot of iterative work, which does not
    work well in version control (too much floating point noise).
    This passes the Design Rules Checker except for a warning from
    each ceoloide footprint not being in the library, a warning for
    the USB cut-out clipping the controller footprint (deliberate),
    and 2 errors about not enough spokes for ground plane zones
    (cofigurable threshold).
    [gamma-omega-tc36k-routed.kicad_pcb]
2025-06-27 Fix ceoloide footprints submodule
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2025-06-27 Exclude RPi Pico controller & screw footprints from BOM & CPL lists
    Using the KiCad JLCPLC Tools plugin for this.
    [gamma-omega-tc36k-routed.kicad_pcb]
2025-06-27 Assign LCSC part number C9900009224 for CPG135001S30 choc hotswap sockets.
    Using the KiCad JLCPLC Tools plugin for this. Currently out of stock.
    Alternative LCSC C5333465 more expensive and effectively out of stock too.
    [gamma-omega-tc36k-routed.kicad_pcb]
2025-06-27 Assign LCSC part number C5333465 for CPG135001S30 choc hotswap sockets.
    More expensive but can actually pre-order this part.
    [gamma-omega-tc36k-routed.kicad_pcb]
2025-07-03 Gerbers ZIP, BOM & positions etc from KiCad Fabrication-Toolkit
    See https://github.com/bennymeg/Fabrication-Toolkit
    Positions not validated - unable to pre-order the hotswap sockets
    and so JLCPLC does not let me proceed with the assembly order.
    [bom.csv, designators.csv, positions.csv]
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2025-07-04 The hot-swap sockets are optional, can solder switches directly
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2025-07-21 enabling capslock LED(Blue) by default.
    - as following, update pre built firmware.
    - this idea from issue #13
2025-07-29 Illustrate the correct hotswap orientation (TC36k PCB)
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2025-07-29 Highlight pin clearance
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2025-09-01 Link to TC36K ZMK firmware too
    This doesn't have the Caps Lock on the blue LED via GPIO pin 25
    (yet), but ZMK is nicer for customising in code with modules.
    QMK/Vial is still better than ZMK Studio and a better starting
    point, so that remains in the build guide.
2025-09-16 Show top case in KiCad (via the controller footprint)
    [gamma-omega-tc36k-routed.kicad_pcb]
2025-09-16 Show bottom case in KiCad (via the controller footprint)
    [gamma-omega-tc36k-routed.kicad_pcb]
2025-09-16 Correct orientation of the choc hotswap 3D models in KiCad
    [gamma-omega-tc36k-routed.kicad_pcb]
2025-09-18 Added covered bottom case.
    - This is identical to Pull Request #24, but the STEP file has been re-exported using Fusion 360 instead of FreeCAD due to too much increased file size.
    [bottom_covered.step]
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2025-09-22 Support both choc v1 & v2 switches
    This fixes an oversight in the TC36K design settings.
    [config.yaml]
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2025-09-22 Workaround footprint oddity with v2 choc support
    [config.yaml]
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2025-09-22 Swap C10, C9, C8 (left) with R4, R3, R8 (right)
    [config.yaml]
2025-09-22 Swap R1 & C3 (top right, cosmetic)
    [config.yaml]
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2025-09-22 Correct comment about Raspberry Pi Pico dimensions
    [config.yaml]
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2025-09-22 Flip battery connections to right-hand side.
    [config.yaml]
2025-09-22 Move the reset button more centrally
    This is tighter to the screw hole, less tucked in the case corner.
    [config.yaml]
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2025-09-22 Swap to Nice Nano footprint to do the tighter wiring
    Can swap back or add the Supermini nRF52840 pins later (within the
    Nice Nano radio keepout).
    [config.yaml]
2025-09-23 Route PCB, add ground plane (copy earlier routing)
    This is currently perfectly aligned on the Ergogen output (no rotation
    noise giving slight offsets), allowing easy updates:
    $ cp output/pcbs/gamma-omega-hesse.kicad_pcb hesse/pcb/gamma-omega-hesse-routed-new.kicad_pcb && \
    /Applications/KiCad/KiCad.app/Contents/Frameworks/Python.framework/Versions/Current/bin/python3 \
    resources/kb_ergogen_helper/ergogen_helper.py copy-traces \
    hesse/pcb/gamma-omega-hesse-routed.kicad_pcb hesse/pcb/gamma-omega-hesse-routed-new.kicad_pcb \
    && open hesse/pcb/gamma-omega-hesse-routed-new.kicad_pcb
    ./src/common/stdpbase.cpp(59): assert ""traits"" failed in Get():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
    [gamma-omega-hesse-routed.kicad_pcb]
2025-09-23 Add Gamma Omega logo on silk screen in radio keepout
    [gamma-omega-hesse-routed.kicad_pcb]
2025-09-23 Use PCM_marbastlib-xp-promicroish:nice_nano_AH_USBup footprint
    [gamma-omega-hesse-routed.kicad_pcb]
2025-09-23 Polish routing at nice nano footprint; mark Supermini nRF52840 hole trio
    [gamma-omega-hesse-routed.kicad_pcb]
2025-09-23 Add cutout to to reach Supermini nRF52840 hole trio (hackery)
    [gamma-omega-hesse-routed.kicad_pcb]
2025-09-23 Remove duplicated automated traces from Ergogen
    [gamma-omega-hesse-routed.kicad_pcb]
2025-09-24 Move Hesse reset switch 1mm in (for case clearance)
    [gamma-omega-hesse-routed.kicad_pcb]
2025-09-24 Link Hesse case step files to controller footprint for viz
    [gamma-omega-hesse-routed.kicad_pcb]
2025-09-30 Enable larger choc v1 or v2 center hole for TC36K in Ergogen
    The stabiliser doesn't seem to fully support the dual
    hotswap or soldering footprints, and is rare on recent
    choc v2 switches anyway - so don't add that. See:
    https://github.com/ceoloide/ergogen-footprints/issues/64
    [config.yaml]
2025-09-30 Enable larger choc v1 or v2 center hole in TC36K KiCad
    Applied the Ergogen change with sed (this was split onto
    different lines, but these match only the 36 times):
    $ sed -i.bak \
    -e 's#(size 3.4 3.4)#(size 5 5)#g' \
    -e 's#(drill 3.4)#(drill 5)#g' \
    tc36k/pcb/gamma-omega-tc36k-routed.kicad_pcb
    [gamma-omega-tc36k-routed.kicad_pcb]
2025-09-30 Update text to TC36K v1.1.0, move traces by centre hole, shorten traces
    Add reset label, restore ground plane
    [gamma-omega-tc36k-routed.kicad_pcb]
2025-09-30 Update TC36K metadata to v1.1.0
    [gamma-omega-tc36k-routed.kicad_pcb]
2025-09-30 TC36K v1.1.0 gerbers ZIP, BOM & positions etc from KiCad Fabrication-Toolkit
    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
    [positions.csv]
2025-10-01 Show infused-kim's Nice Nano v2 3D model in KiCad
    Note offest and rotation, probably as I swapped out their Ergogen footprint
    for this more detailed one.
    [gamma-omega-hesse-routed.kicad_pcb]
2025-10-06 Use KiCad's 3D model for JST PH 2.0 battery connector
    [gamma-omega-hesse-routed.kicad_pcb]
2025-10-06 Top case for 'Hesse' Bluetooth variant (joint effort)
    Based on the original top case with the following changes:
    * Moved rib beams for new battery compartment.
    * Moved beam for new reset button.
    * New hole for reset button.
    * Head room for reset switch.
    * LED funnels in Hesse top-case (0.9mm thick skin) inspired by
    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
    [top-hesse.step]
2025-10-07 Bottom case for 'Hesse' Bluetooth variant (joint effort)
    Based on the original covered bottom case with the following changes:
    * Simlified the hotswap cutouts no covered (lighter this way).
    * Added 1.4mm battery resess cutout
    * Added cutout for the JST PH 2.0 battery connector legs
    * Added cutout for the reset button legs
    * Added cutout for the Nice!Nano v2 or clone middle pins
    This retains the full length header cutouts for the Raspberry Pi Pico,
    so should still work with the original or TC36K PCB too.
    Done in a mixture of tools, initially editing the original case in
    FreeCAD (peterjc) which made the file much larger. Imported back
    into AF, glitches cleaned up, and re-exported as a small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
    [bottom-hesse.step]
2025-10-07 Fix top case offset for KiCad 3D model usage
    [gamma-omega-hesse-routed.kicad_pcb]
2025-10-07 Assign LCSC parts for hotswap, JST battery, and reset switch
    [gamma-omega-hesse-routed.kicad_pcb]
2025-10-07 Hesse Gerbers ZIP, BOM & positions etc from KiCad Fabrication-Toolkit
    and so JLCPLC would not let me proceed with an assembly order.
    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
    [bom.csv, designators.csv, positions.csv]
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
